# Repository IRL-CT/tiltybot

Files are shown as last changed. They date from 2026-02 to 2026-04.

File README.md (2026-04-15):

# TiltyBot

A smartphone-controlled robot platform built on the ESP32-S3 and Dynamixel XL330 servo motors. The robot hosts its own Wi-Fi network and serves a browser-based control interface — no app install required.

Building on Rei Lee's [ConeBot](https://github.com/rei039474/ConeBot).

<p>
  ConeBot waddling
  Pan-tilt gyro control
  Two-wheeled drive mode
</p>

## Guides

- **[TiltyBot Intro](TiltyBot_Intro_EN.md)** — connect and use
- **[TiltyBot Assembly & Advanced](TiltyBot_Advanced_EN.md)** — build, flash, modify

## What it does

Connect your phone to the robot's Wi-Fi, open `https://192.168.4.1`, and pick a mode:

- **Drive** — joystick differential drive
- **Tilty** — phone gyro pan/tilt (Android) or manual sliders
- **2-Motor** — direct position control
- **Puppet** — one robot mirrors another via ESP-NOW
- **Sound** — TTS, soundboard, recording
- **Calibrate** — set motor home position and limits

## Hardware

- [Waveshare ESP32-S3-Zero](https://www.waveshare.com/esp32-s3-zero.htm)
- 2× [Dynamixel XL330-M077-T](https://robotis.us/dynamixel-xl330-m077-t/)
- USB-C cable and power source

## Quick start

```bash
git clone https://github.com/imandel/tiltybot.git
cd tiltybot
pio run -e tiltybot -t upload
pio run -e tiltybot -t uploadfs
```

Connect your phone to the `BOT-*` Wi-Fi (password: `12345678`), open `https://192.168.4.1`.

## License

MIT

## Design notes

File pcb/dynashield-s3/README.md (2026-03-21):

# Dynashield S3

PCB adapter board for mounting a Waveshare ESP32-S3-Zero underneath, with a Dynamixel XL330 connector on top.

## Setup

1. Download the ESP32-S3-Zero part from [SnapEDA](https://www.snapeda.com/parts/ESP32-S3-Zero/Waveshare%20Electronics/view-part/)
2. Import the `.kicad_sym` and `.kicad_mod` files into KiCad (Preferences → Manage Symbol/Footprint Libraries → Add)
3. Open `dynashield-s3.kicad_sch` in KiCad
4. Add the ESP32-S3-Zero symbol and the B3B-EH-ALFSN connector (from KiCad's built-in Connector library)

## Wiring

| ESP32-S3-Zero | Net | Dynamixel Connector |
|---|---|---|
| GPIO1 (pin 4, left side) | DATA | Pin 3 (Data) |
| GPIO2 (pin 5, left side) | DATA | Pin 3 (Data) |
| 5V (pin 1, top left) | VDD | Pin 2 (VDD) |
| GND (pin 2, top left) | GND | Pin 1 (GND) |

GPIO1 and GPIO2 are tied together on the PCB — they share the same net (DATA) which connects to the Dynamixel's half-duplex data line.

## Board layout

The ESP32-S3-Zero mounts on the **bottom** of the PCB using its castellated hole pads (pins 1 and 2 side — 5V, GND, 3V3, GP1-GP6). The Dynamixel connector sits on the **top**.

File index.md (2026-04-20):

# TiltyBot Lab

## What is TiltyBot?

TiltyBot is a small expressive robot you control from your phone's browser. It has two servo motors and a microcontroller.

TiltyBot

### Parts

- **ESP32-S3-Zero** — a small Wi-Fi microcontroller ([Waveshare](https://www.waveshare.com/esp32-s3-zero.htm))
- **2× Dynamixel XL330-M077-T** — smart servo motors ([Robotis](https://robotis.us/dynamixel-xl330-m077-t/))
- **Hinge frame** — connects the two motors in a pan/tilt configuration ([Robotis](https://en.robotis.com/shop_en/item.php?it_id=903-0302-000))
- **USB-C battery pack**
- **Whatever you build around it** — cardboard, tape, etc

### How it's connected

```
   ┌─────────┐  USB-C  ┌──────────┐ 3-wire  ┌──────────┐ 3-wire  ┌──────────┐
   │ Battery ├────────►│ ESP32-S3 ├────────►│ Motor 1  ├────────►│ Motor 2  │
   └─────────┘         └────┬─────┘  bus    │  (Tilt)  │   bus   │  (Pan)   │
                            ┆               └──────────┘         └──────────┘
                            ┆ Wi-Fi
                            ┆ HTTPS
                       ┌────┴─────┐
                       │  Phone   │
                       │ (Browser)│
                       └──────────┘
 ```

The motors daisy-chain together on a single 3-wire bus (power + ground + data). The ESP32 runs a Wi-Fi network and HTTPS server which your phone connects to directly.

### The motors

These are [Dynamixel XL330-M077-T](https://robotis.us/dynamixel-xl330-m077-t/) servos. They're assembled in a pan/tilt configuration. You can think of it as:

- A **head and neck** — nod and look around
- A **torso and legs** — lean and twist
- A **short stubby snake** — two joints that wiggle

You can decide what each motor corresponds to.

### Set up

We've assembled the hardware, flashed the firmware, and calibrated each robot. 

- Firmware: [`src/tiltybot/main.cpp`](src/tiltybot/main.cpp)
- Web UI: [`data/`](data/) (HTML/CSS/JS served from the ESP32's filesystem)
- Full build/flash instructions: [TiltyBot Assembly & Advanced](TiltyBot_Advanced_EN.md)

---

## 1. Connect to Your Robot

Your robot automatically starts running when you connect it to power, and it is already serving a webpage which enables the robot to be remotely controlled. Look for the WiFi network with the same label as your robot.
Connect to it from a phone (android works best!):

1. Open Wi-Fi settings, find your robot's network (starts with `BOT-` and matches the sticky note color)
2. Password: `12345678`
3. Turn off your phone's cellular network
4. Open `https://192.168.4.1` in your browser
5. Accept the certificate warning (tap Advanced → Proceed)
6. You should see the TiltyBot menu served up by your robot

<p>
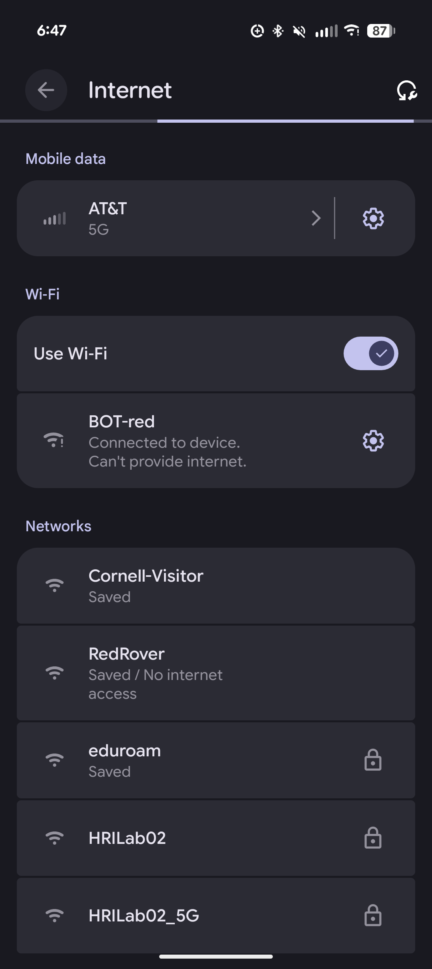
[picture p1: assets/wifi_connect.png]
Wi-Fi settings
  
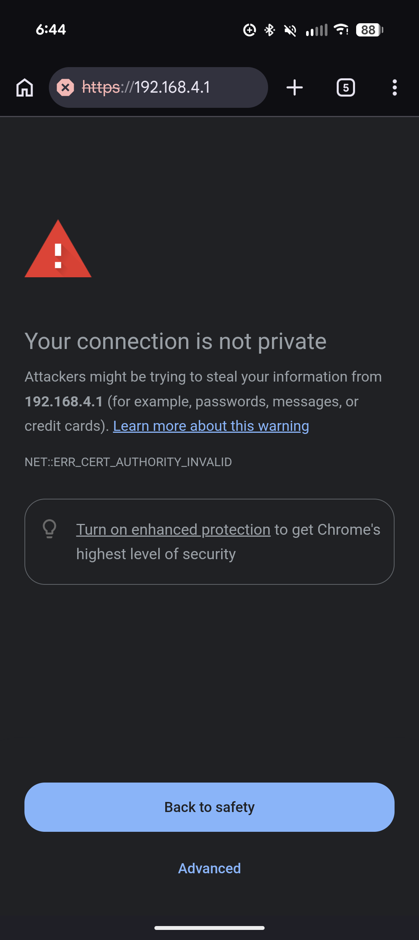
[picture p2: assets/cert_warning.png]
Certificate warning
  
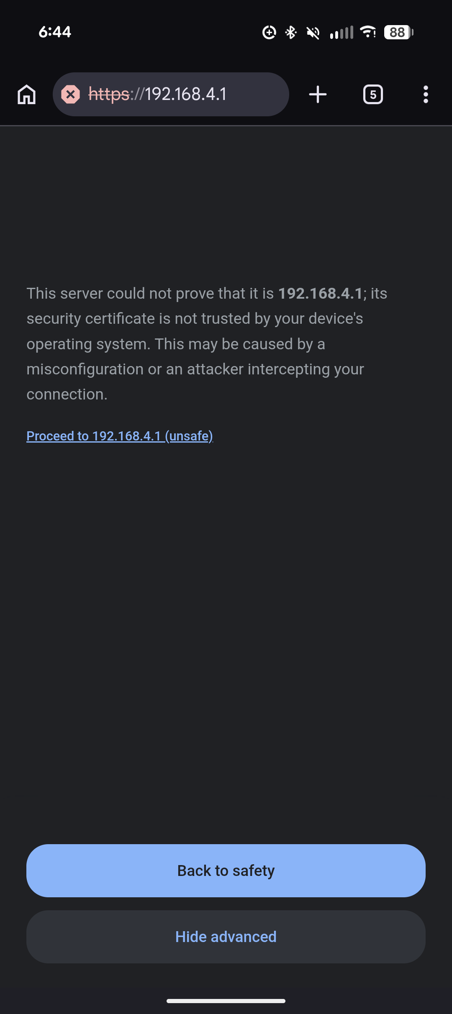
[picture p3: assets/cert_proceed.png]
Tap Proceed
  
</p>

You should see the TiltyBot menu:

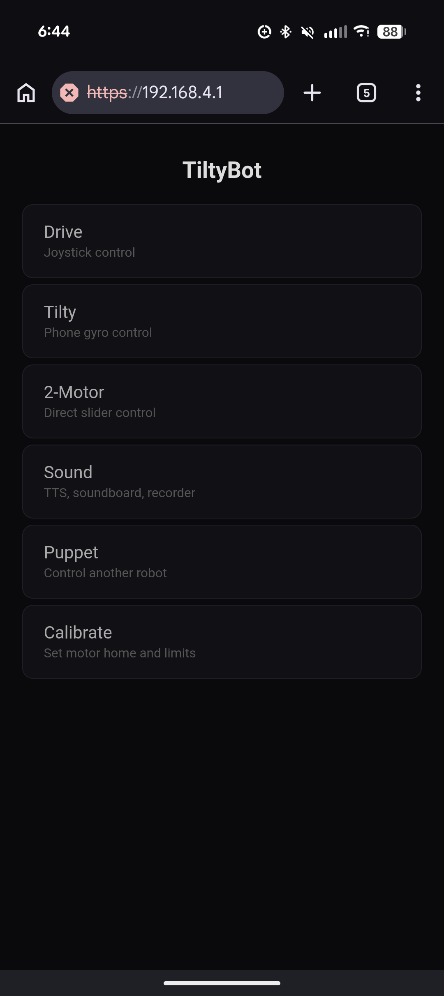
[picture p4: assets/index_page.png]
TiltyBot menu


---

## 2. Explore Motion

Your robot has several control modes. How you wizard a robot can shape what kinds of affect it can express. Try each of them and see what interactions feel natural.

### 2A. Tilty

Open **Tilty** from the menu. Use the sliders to control tilt (up/down) and pan (left/right).

With an Android phone, enable the **Gyro** checkbox. Your phone's orientation now controls the robot directly. Tilt and angle your phone to wizard the robot.

<p>
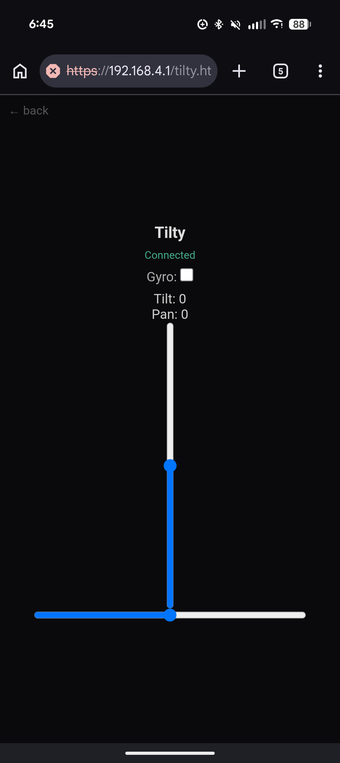
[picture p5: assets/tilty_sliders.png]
Tilty sliders
  
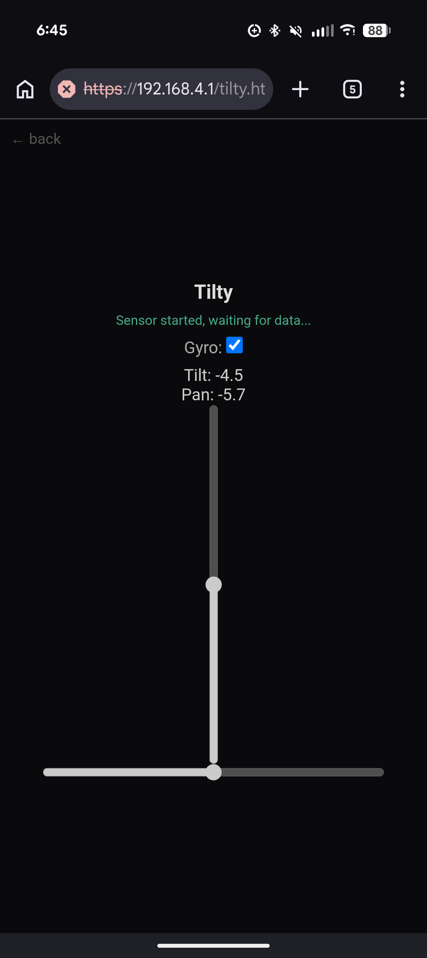
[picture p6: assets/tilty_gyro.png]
Tilty gyro
  
</p>

Tilty in action

> **Under the hood:** Gyro mode uses [`RelativeOrientationSensor`](https://developer.mozilla.org/en-US/docs/Web/API/RelativeOrientationSensor) to get hardware quaternions from the phone's IMU, then decomposes a delta quaternion into YXZ Euler angles. This avoids gimbal lock. If you're curious the math is in `data/tilty.html`.

### 2B. 2-Motor

Open **2-Motor** from the menu. Two sliders, one per motor. This gives you a clear understanding what each motor can do physically.

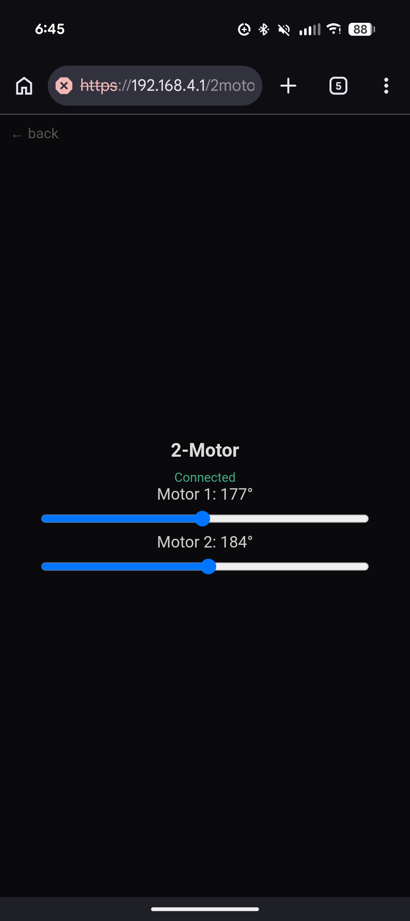
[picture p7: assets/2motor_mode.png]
2-Motor mode


### 2C.  Drive

If you are more interested in a mobile robot than a desktop robot, we have pre-assembled motor pairs configured for driving. Take them, unplug your tiltybot from the esp32 and plug the wheels in instead. You will have to attach the motors to a piece of cardboard to act as a base.

Open **Drive** from the menu. Check the **Active** box, then use the joystick to drive. The robot uses differential drive — both motors spinning the same direction turns, opposite directions goes straight.

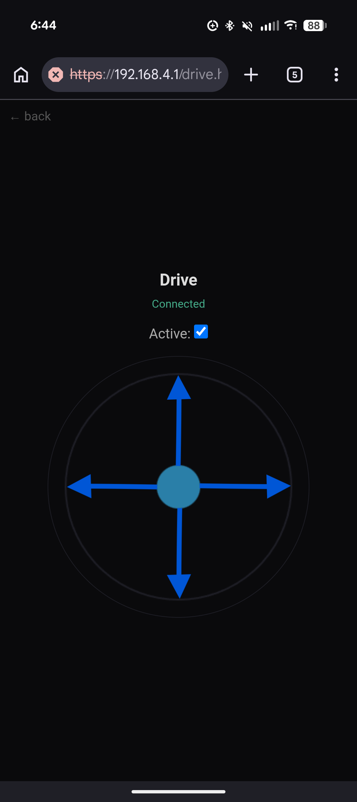
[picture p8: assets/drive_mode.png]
Drive mode


Drive demo

> **Under The Hood:**  A 300ms watchdog stops the motors if the client connection drops. Robots should ALWAYS use a watchdog timer.

### Questions

- How does each control mode change what the robot can express?
- What would you want the robot to do that you can't do yet?

---

## 3. Puppet Mode

Find another group. You'll pair two robots together. One will be the controller whicy you can direct by hand, the other will be a puppet and mirror its actions.

### Setup

1. On **both** robots, open the **Puppet** page
2. Pick the **same emoji** on both
3. One robot: tap **Controller** — its motors release, you move it by hand
4. Other robot: tap **Puppet** — it follows the controller's movements
5. Tap **Stop** on either robot when done

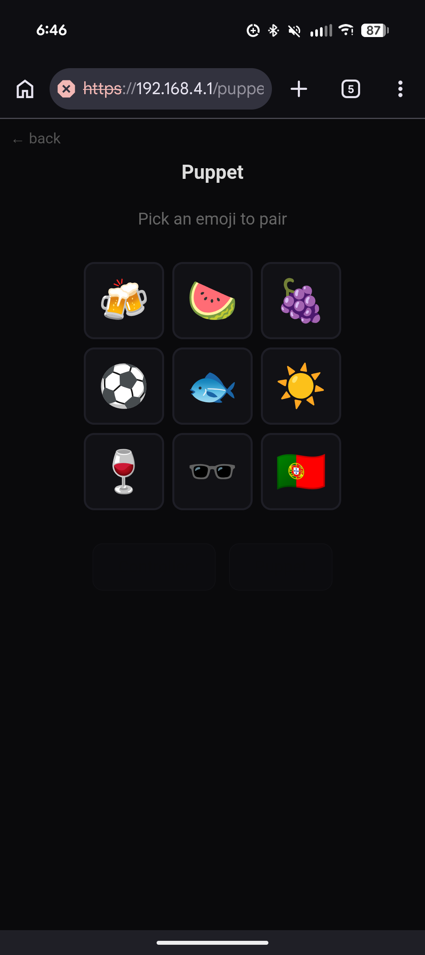
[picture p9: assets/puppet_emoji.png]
Puppet emoji selection


### Try it

- Have one person wizard the controller while someone from the other group interacts with the puppet
- Switch roles

> **Under The Hood:** Puppet mode uses ESP-NOW, a peer-to-peer wireless protocol that runs alongside Wi-Fi with ~1–5ms latency. The controller reads motor positions, converts to degrees, and broadcasts at ~100Hz. The puppet converts back using its own calibration. See the `PuppetPacket` struct in `main.cpp`. You can puppet multiple robots simultaneously. How would the interaction change with two, three, five, fivehundred tiltybots?

---

## 4. Sound

**When you get to this step ask Ilan for a speaker.**

Sound mode is designed for a **second operator**. One person controls the robot's movement (any mode), while another person triggers sounds from a second phone connected to the same robot.

### Setup

1. Connect a second phone to the same `BOT-*` network
2. Connect your phone's Bluetooth to the speaker. The speaker should show up as `MT`
3. Open **Sound** from the menu
4. Allow microphone access if prompted
5. Turn the speaker on and put it in pairing mode by holding the button on the bottom until the light flashes.

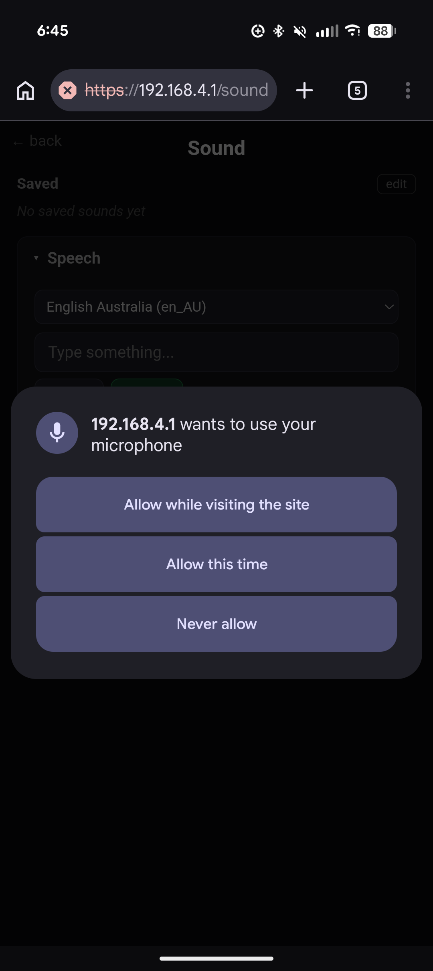
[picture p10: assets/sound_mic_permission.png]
Microphone permission


### What's available

- **Speech** — type text, pick a voice, tap Speak. Tap + Save to keep phrases for quick access.
- **Soundboard** — 24 synthesized robot sounds (beeps, chirps, affirmations, etc). Tap to play, tap + to save to the top bar.
- **Record** — record from the microphone or load audio files from your phone.

You can find sounds all over the internet. I am a fan of https://freesound.org/

Saved sounds appear in the **Saved** section at the top for one-tap playback during an interaction.

<p>
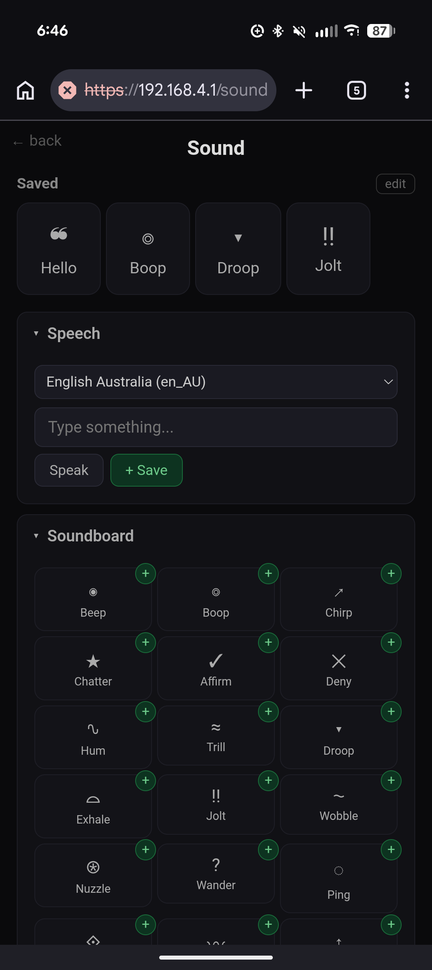
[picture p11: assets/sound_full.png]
Sound page
  
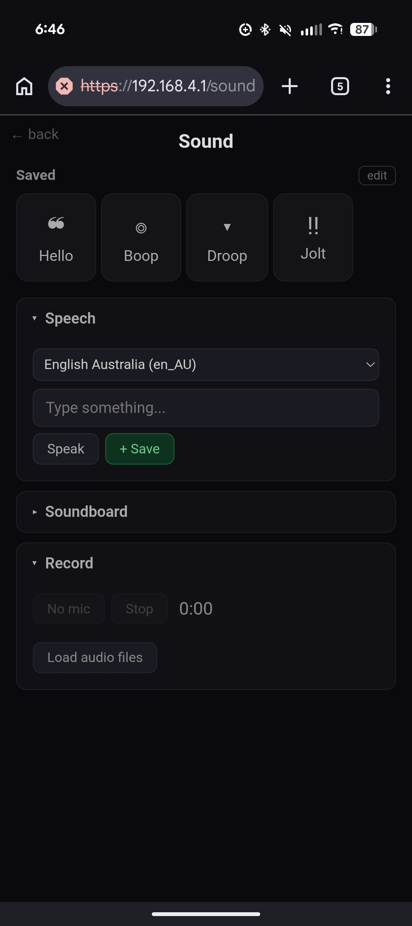
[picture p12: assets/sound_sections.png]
Sound sections
  
</p>

### Try it

- One person drives or puppets, the other does sound
- Practice synchronizing your actions. Plan out what motions and sounds should occur in tandem. Try doing improv with another member of your group. 
- Try an interaction with just motion, then just sound then try combining them.

### Questions
- When does sound help? When does it get in the way?
- How does operating two channels (motion + sound) change wizarding?

> **Under the hood:** TTS uses the browser's built-in [`SpeechSynthesis`](https://developer.mozilla.org/en-US/docs/Web/API/SpeechSynthesis) API. Soundboard effects are generated with the Web Audio API ([`OscillatorNode`](https://developer.mozilla.org/en-US/docs/Web/API/OscillatorNode), [`BiquadFilterNode`](https://developer.mozilla.org/en-US/docs/Web/API/BiquadFilterNode), etc). See `data/sound.html`.

---

## 5. Design an Interaction

Use what you've explored to design a short interaction.

How would a tiltybot take your order at a restuarant? How might it direct you to the right classroom in driving mode?

ConeBot

### Pick your setup

- Which control mode?
- Who is the robot interacting with? Someone from your group? A stranger?
- What is the context?
- What is the robot's role? 

### Design it

- What happens? Write down 2–3 sentences describing the interaction.
- What is the robot doing and why?
- What do you expect the person to do?

### Run it

- Try it at least once within your group
- Then try it with someone who wasn't involved in the design
- Did people respond the way you expected?
- What would you change?
- What did the control mode make easy or hard?

---

*— Coffee break —*

---

## 6. Check-in

Brief group share. What did you try? What didn't work?

---

## 7. Refine and Record

You have the rest of the afternoon to iterate on your interaction and capture it on video.

### Goals

- Refine your interaction based on what you learned
- Try it with people! 
- - Try a different setting (hallway, doorway, desk, open space)
- **Record video** — capture the full interaction, not just the robot. Include the person's reactions and the context.
- These can be naturalistic or acted. You want to clearly explore the *interaction*
- What research questions did these explorations inspire?
- You'll present these tomorrow

> If you're interested in automating interactions, modifing the control interfaces or extending tiltybot talk to Ilan about it!

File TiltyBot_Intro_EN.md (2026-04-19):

# TiltyBot Intro

## [TiltyBot Assembly & Advanced →](TiltyBot_Advanced_EN.md)

## What TiltyBot Is

TiltyBot is a small robot built from an ESP32-S3 microcontroller and two Dynamixel XL330 servo motors. It can be assembled as a mobile robot or a minimalist desktop robolt.

The robot runs its own Wi-Fi network and serves a phone browser-based control interface.

TiltyBot overview

ConeBot demo

## How to Connect

1. On your phone, open Wi-Fi settings and look for a network starting with `BOT-` (e.g., `BOT-red`, `BOT-blue`)

2. Connect to it. The password is `12345678`. Your phone will say it can't provide internet. Turn of cellular data.

Wi-Fi settings showing BOT-red

3. Open a browser and go to `https://192.168.4.1`

4. You will see a certificate warning. Tap **Advanced**, then **Proceed to 192.168.4.1 (unsafe)**. The robot uses a self-signed certificate so the browser can access phone sensors like the gyroscope.

Certificate warning

Tap Advanced, then Proceed

5. You should see the TiltyBot main menu:

TiltyBot index page

## Modes

### Drive

Differential drive control using an on-screen joystick. Click the checkbox to activate the motors, then touch and drag to steer.

Drive mode

Drive demo

### Tilty (Android only)

Controls the robot's pan and tilt using your phone's orientation. Hold your phone and tilt it — the robot follows.

> Gyro control requires an Android device. Manual sliders are available on any device as a fallback.

**Before using Tilty mode, calibrate the robot.**

Open the Calibrate page from the main menu:

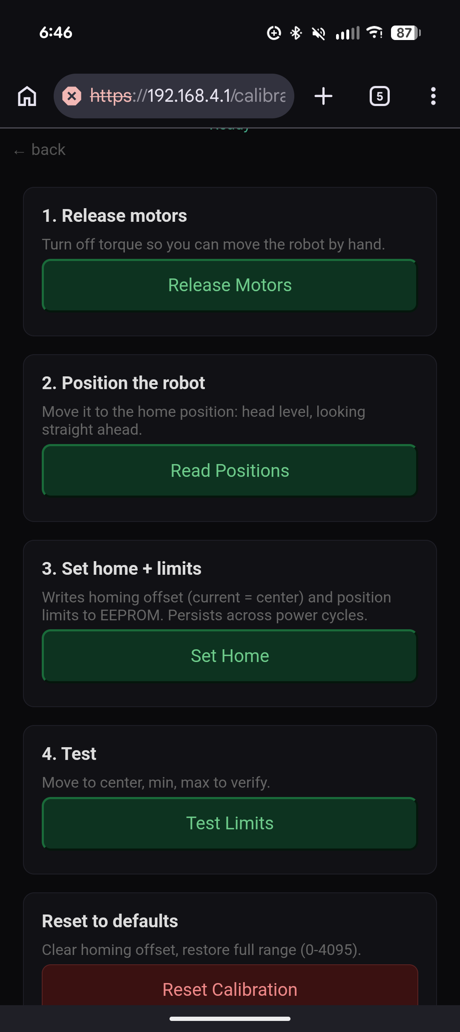
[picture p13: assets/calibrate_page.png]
Calibrate page


1. Tap **Release Motors** — this turns off motor torque so you can move the head by hand
2. Physically position the robot's head to the desired neutral pose: level, facing straight ahead
3. Tap **Read Positions** to confirm the motor values
4. Tap **Set Home** — this writes the current position as the new center to motor memory
5. Tap **Test Limits** — the robot moves through its range so you can verify it looks correct

Calibration persists across power cycles. You only need to redo it if you physically reassemble the robot.

Once calibrated, open Tilty mode. Use the sliders for manual control:

Tilty mode with sliders

Or enable the **Gyro** checkbox to control with phone orientation:

Tilty mode with gyro enabled

Tilty demo

### 2-Motor

Direct slider control of both motors independently. Useful for testing motor response or exploring range of motion.

2-Motor mode

### Puppet (two bots)

One robot mirrors another's movements in real time. You move the controller robot by hand, and the puppet robot follows.

**Setup:**

1. Open the Puppet page on both robots (from two phones, each connected to its own bot's Wi-Fi)
2. Pick the **same emoji** on both robots

Puppet emoji selection

3. On one robot, tap **Controller** — its motors release so you can move it by hand
4. On the other robot, tap **Puppet** — it begins following the controller's movements
5. Tap **Stop** on either robot to end

For best results, calibrate both robots before using puppet mode.

### Sound

We provide a basic audio control interface for use with a small bluetooth speaker. You can do text-to-speech, a "robot" soundboard, audio recording, and file playback.

Sound mode is designed for a **second operator**. One person controls the robot's movement (via Drive, Tilty, or Puppet) while another person operates Sound mode from a second phone connected to the same robot.

The first time you open Sound, your browser will ask for microphone permission. Tap **Allow while visiting the site** if you want to use the recorder.

Microphone permission

Sound page with saved sounds and all sections

Sound page showing collapsed sections

## If Something Doesn't Work

| Problem | Try |
|---|---|
| Can't find the Wi-Fi network | Make sure you're close to the robot and it's powered on |
| Page won't load | Confirm you're on the `BOT-*` network, go to `https://192.168.4.1` |
| Certificate error won't go away | Try a different browser (Chrome works best) |
| Motors don't respond | Reload the page, or try 2-Motor mode to check basic connectivity |
| Tilty gyro doesn't work | Confirm you're on an Android device. Toggle the Gyro checkbox off and on |
| Puppet doesn't follow | Check both robots selected the same emoji. Recalibrate both |
| Robot behaves strangely after reassembly | Recalibrate |

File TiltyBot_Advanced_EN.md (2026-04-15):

# TiltyBot Assembly & Advanced

## Hardware

- [Waveshare ESP32-S3-Zero](https://www.waveshare.com/esp32-s3-zero.htm) (ESP32-S3, 4MB Flash, 2MB PSRAM)
- 2× [Dynamixel XL330-M077-T](https://robotis.us/dynamixel-xl330-m077-t/) servo motors
- [XL330 Hinge Frame](https://www.robotis.us/fpx330-h101-4pcs-set/)
- USB-C cable
- Wheels, caster wheels
- Cardboard, tape, and whatever else you want to build with

### Wiring

The motors daisy-chain together and connect to the ESP32-S3-Zero via 3 wires:

| Dynamixel XL330 Pin | Signal | ESP32-S3-Zero |
|---|---|---|
| Pin 1 — GND | Ground | **GND** |
| Pin 2 — VDD | Power (5V) | **5V** |
| Pin 3 — Data | Half-duplex serial | **GPIO1 + GPIO2** (tied together) |

GPIO1 (TX) and GPIO2 (RX) are next to each other on the left side of the board. Both connect to the single Dynamixel Data wire for half-duplex communication.

## Software Setup

Install:

- [Git](https://git-scm.com/)
- [PlatformIO](https://platformio.org/) — either as a VS Code extension or CLI-only

Clone the repository:

```bash
git clone https://github.com/imandel/tiltybot.git
cd tiltybot
```

Verify the build:

```bash
pio run -e tiltybot
```

## Motor Setup

Each motor needs a unique ID. Flash the motor setup tool:

```bash
pio run -e motor_setup -t upload
pio device monitor -b 115200
```

Connect **one motor** at a time:

1. Connect Motor 1, type `1` → configures as ID 1 (LED blinks, motor moves to confirm)
2. Disconnect Motor 1, connect Motor 2, reset board, type `2` → configures as ID 2
3. Daisy-chain both motors, reset board, type `t` → runs full test

**Motor 1 = tilt** (nod up/down), **Motor 2 = pan** (rotate left/right).

## Build / Flash / UploadFS

Upload firmware:

```bash
pio run -e tiltybot -t upload
```

Upload web UI and certificates to the filesystem:

```bash
pio run -e tiltybot -t uploadfs
```

Both steps are needed when setting up a new robot. After that, you only need to re-upload whichever part you changed.

**If the ESP32-S3 won't enter download mode** (upload fails with "No serial data received"):

1. Hold **BOOT**
2. Tap **RESET**
3. Release **BOOT**
4. Retry the upload command

## Configuration (`BOT_SSID`)

Each robot's Wi-Fi network name is set at build time:

```bash
PLATFORMIO_BUILD_FLAGS='-DBOT_SSID="BOT-yourname"' pio run -e tiltybot -t upload
```

The default (if no flag is set) is defined in `main.cpp`:

```c
#define BOT_SSID "YOURGROUPNAME"
```

The Wi-Fi password is `12345678`.

## Project Layout

```
tiltybot/
├── src/
│   ├── tiltybot/main.cpp      # Main firmware (all control modes)
│   └── motor_setup/main.cpp   # Motor ID assignment utility
├── data/                      # Web UI (served from LittleFS)
│   ├── style.css              # Shared styles
│   ├── index.html             # Landing page
│   ├── drive.html             # Drive mode
│   ├── tilty.html             # Tilty mode
│   ├── 2motor.html            # 2-Motor mode
│   ├── puppet.html            # Puppet mode
│   ├── sound.html             # Sound mode
│   └── calibrate.html         # Calibration
├── certs/                     # Self-signed SSL certificates
├── partitions.csv             # Custom partition table (4MB flash)
└── platformio.ini             # Build configuration
```

## System Architecture

- The ESP32 runs as a **Wi-Fi access point** and HTTPS server
- Web pages are stored on **LittleFS** and served to the browser
- Browser control pages communicate with the firmware over **WebSocket**
- Each mode has its own WebSocket endpoint (`/ws/drive`, `/ws/tilty`, `/ws/2motor`)
- Drive mode uses **Dynamixel Sync Write** to update both motors in a single bus packet
- Tilty mode uses `RelativeOrientationSensor` (Android) with delta quaternion decomposition for gimbal-lock-free pan/tilt control
- Puppet mode uses **ESP-NOW** for direct robot-to-robot communication (~1–5ms latency, ~100Hz). Emoji selection acts as a pairing filter. Packets carry angles in degrees; each robot maps through its own calibration

## Debugging / Logs

```bash
pio device monitor -b 115200
```

Key log lines:

| Log prefix | Meaning |
|---|---|
| `Motor mode -> DRIVE/POSITION` | Mode switch on WebSocket connect |
| `DRIVE moving: ...` | Joystick input started |
| `DRIVE -> stop: ...` | Joystick released, writing zeros |
| `DRIVE watchdog: ...` | No client frame for 300ms, emergency stop |
| `DRIVE X.XHz ...` | Periodic drive status (every 2s) |
| `TILTY ...` | Tilty/2-motor position update |
| `PUPPET TX: ...` | Controller broadcasting position |
| `ESP-NOW rx ...` | Puppet receiving data |
| `CALIB: ...` | Calibration operations |

If behavior seems wrong after physical changes, recalibrate before deeper debugging.

## CLI Reference

```bash
# Build
pio run -e tiltybot
pio run -e motor_setup

# Upload
pio run -e tiltybot -t upload
pio run -e tiltybot -t uploadfs
pio run -e motor_setup -t upload

# Custom SSID
PLATFORMIO_BUILD_FLAGS='-DBOT_SSID="BOT-red"' pio run -e tiltybot -t upload

# Specify port
pio run -e tiltybot -t upload --upload-port /dev/cu.usbmodem101

# Monitor
pio device monitor -b 115200

# Clean / erase
pio run -e tiltybot -t clean
pio run -e tiltybot -t erase
```

## Dependencies

Managed automatically by PlatformIO (see `platformio.ini`):

- [PsychicHttp](https://github.com/hoeken/PsychicHttp) — HTTPS server with WebSocket support
- [Dynamixel_XL330_Servo_Library](https://github.com/rei039474/Dynamixel_XL330_Servo_Library.git) — Motor control
- [ArduinoJson](https://github.com/bblanchon/ArduinoJson) — JSON parsing

## Notes

- HTTPS is required for gyroscope access — browsers only allow sensor APIs in secure contexts
- Turn off cellular data on your phone so it doesn't drop the robot's network
- Corporate/managed phones may not work due to network restrictions
- To regenerate the SSL certificate:
  ```bash
  openssl req -x509 -newkey ec -pkeyopt ec_paramgen_curve:prime256v1 \
    -keyout data/server.key -out data/server.crt -days 3650 -nodes \
    -subj "/CN=tiltybot.local"
  ```

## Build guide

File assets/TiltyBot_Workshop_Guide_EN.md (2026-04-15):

# TiltyBot Workshop Guide

A hands-on workshop for building and interacting with a smartphone-controlled robot using an ESP32-S3, Dynamixel motors, and open-source software.

---

## Table of Contents

1. [Preparation](#1-preparation)
2. [Software Setup — Building the Base Robot](#2-software-setup--building-the-base-robot)
3. [Hardware Assembly](#3-hardware-assembly)
4. [Calibration](#4-calibration)
5. [Puppet Mode](#5-puppet-mode)
6. [Interaction Design](#6-interaction-design)

---

## 1. Preparation

This section covers everything you need to do before the workshop begins. If you get stuck on any step, don't worry — these can also be completed in person at the start of the workshop.

### Before You Begin

- You will use a **personal smartphone** to control the robot. Corporate/managed phones may not work due to security restrictions.
- **Gyro tilty mode requires Android** (uses RelativeOrientationSensor). Manual sliders work on any device.

### Step 1: Install Tools

You can use VS Code with PlatformIO, or just the CLI.

**Option A: VS Code** (recommended for beginners)

- [Visual Studio Code](https://code.visualstudio.com/)
- [PlatformIO](https://platformio.org/) extension — install from VS Code Extensions tab
- [Git](https://git-scm.com/download/win) (Windows) / Git is pre-installed on most Macs

**Option B: CLI only**

- [Git](https://git-scm.com/)
- PlatformIO Core:
  ```bash
  pip install platformio
  # or
  curl -fsSL -o get-platformio.py https://raw.githubusercontent.com/platformio/platformio-core-installer/master/get-platformio.py
  python3 get-platformio.py
  ```

### Step 2: Clone the TiltyBot Repository

Clone the project repository to a convenient location on your computer (e.g., your Desktop).

1. Open a terminal (or right-click your desired folder and select **Git Bash Here** on Windows).

<!-- TODO: update screenshot for new repo -->
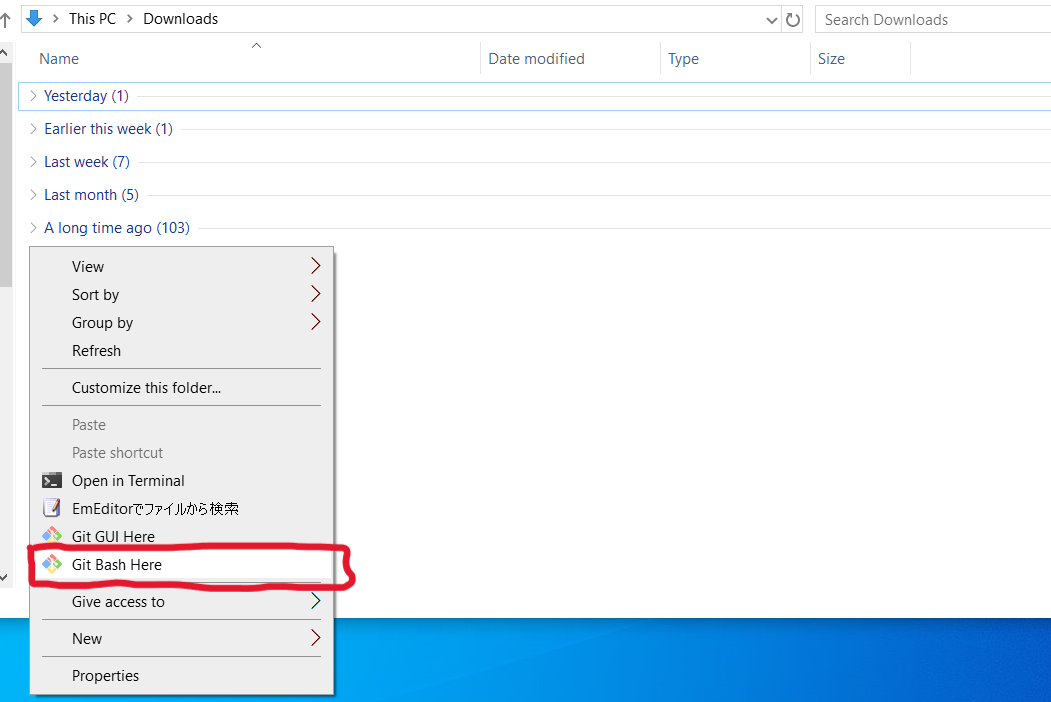
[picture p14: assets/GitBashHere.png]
Opening Git Bash from a folder


2. Run the following command:

```
git clone https://github.com/imandel/tiltybot.git
```

### Step 3: Install PlatformIO (VS Code only)

If using VS Code:

1. Go to **View → Extensions**. Search for **PlatformIO** and install it.
2. Click the PlatformIO icon (ant icon) in the left sidebar to trigger initialization. Wait until it finishes.
3. Click **Reload Now** when prompted.

### Step 4: Build the Project

**VS Code:** Open the `tiltybot` folder in PlatformIO, then click the **Build button** (checkmark at the bottom).

**CLI:**

```bash
cd tiltybot
pio run -e tiltybot
```

Wait for "SUCCESS." Preparation is now complete!

---

## 2. Software Setup — Building the Base Robot

### Step 1: Configure Motors

Each Dynamixel motor needs a unique ID. We'll use a setup tool to assign them.

**Important:** Motor 1 = **tilt** (nod up/down), Motor 2 = **pan** (rotate left/right).

1. Upload the motor setup tool:

   ```bash
   pio run -e motor_setup -t upload
   ```

2. Open the Serial Monitor:

   **VS Code:** Click the plug icon at the bottom status bar.

   **CLI:**
   ```bash
   pio device monitor -b 115200
   ```

   You'll see:

```
========================================
  TILTYBOT MOTOR SETUP
========================================

Options:
  1 - Configure this motor as Motor 1
  2 - Configure this motor as Motor 2
  t - Test both motors (daisy-chained)
```
If not press the reset button on the ESP32 while connected to the serial monitor.

3. With **one motor connected**, type `1` and press Enter. The motor's LED will blink and it will rotate back and forth to confirm.

4. Disconnect the first motor. Connect the **second motor**. Reset the board (press the reset button or unplug/replug USB). Type `2` and press Enter.

5. Daisy-chain both motors together (plug Motor 2 into Motor 1's other port, Motor 1 connects to the board). Reset the board. Type `t` to run the full test:
   - Both LEDs blink individually
   - Position mode: both motors move through several positions
   - Drive mode: both motors spin forward, backward, slow, and max speed

If the test passes, your motors are ready!

### Step 2: Set Wi-Fi Name

The robot hosts its own local Wi-Fi network (no internet required). You'll connect your phone to this network to control the robot.

Set the SSID at build time:

```bash
PLATFORMIO_BUILD_FLAGS='-DBOT_SSID=\"BOT-yourname\"' pio run -e tiltybot -t upload
```

Or edit `src/tiltybot/main.cpp` directly and change:

```c
#define BOT_SSID "YOURGROUPNAME"
```

The password defaults to `12345678` (must be 8+ characters).

### Step 3: Upload SSL Certificates and HTML Pages

The robot uses HTTPS so your phone's gyroscope can work in the browser. Upload the filesystem (SSL certificates + all HTML pages):

```bash
pio run -e tiltybot -t uploadfs
```

### Step 4: Upload Firmware

```bash
pio run -e tiltybot -t upload
```

Or with a custom SSID:

```bash
PLATFORMIO_BUILD_FLAGS='-DBOT_SSID=\"BOT-yourname\"' pio run -e tiltybot -t upload
```

### Step 5: Connect Your Phone to the Robot

1. On your phone, go to Wi-Fi settings and connect to the network you configured in Step 2. Ignore any "No Internet" warnings.

2. Open a browser and navigate to `https://192.168.4.1`

3. You'll see a security warning about the self-signed certificate. Tap **Advanced** → **Proceed** (or equivalent for your browser).

4. The index page shows all available modes — pick one!

<!-- TODO: screenshot of index page on phone -->

**Tips:**
- Turn off cellular data on your phone to prevent it from automatically switching away from the robot's network.
- Disconnect from any VPN before connecting.

### Step 6: Test the 2-Motor Mode

Start with **2-Motor mode** to verify everything works. Move the sliders — both motors should respond.

You're now ready to assemble.

---

## 3. Hardware Assembly

Choose one of the two robot types to build:

| Driving Robot | Tilty Robot |
|---|---|
| Mobile robot on wheels | Dashboard robot that tilts and pans |

### Wiring

Connect the ESP32-S3-Zero to the Dynamixel motors:

| Dynamixel XL330 Pin | Signal | ESP32-S3-Zero |
|---|---|---|
| Pin 1 — GND | Ground | **GND** |
| Pin 2 — VDD | Power (5V) | **5V** |
| Pin 3 — Data | Half-duplex serial | **GPIO1 + GPIO2** (tied together) |

<!-- TODO: photo of wiring close-up -->

The two motors daisy-chain together — connect Motor 2 to the other port on Motor 1.

### Driving Robot

1. **Attach axles:** Screw the white axle pieces onto each motor using the provided screws.

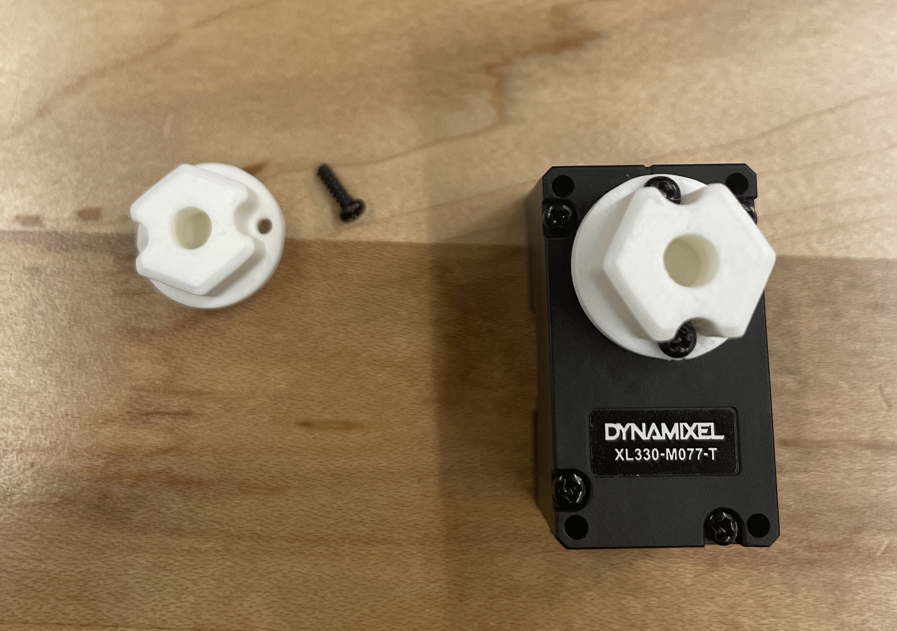
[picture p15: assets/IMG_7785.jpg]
Motor with axle piece

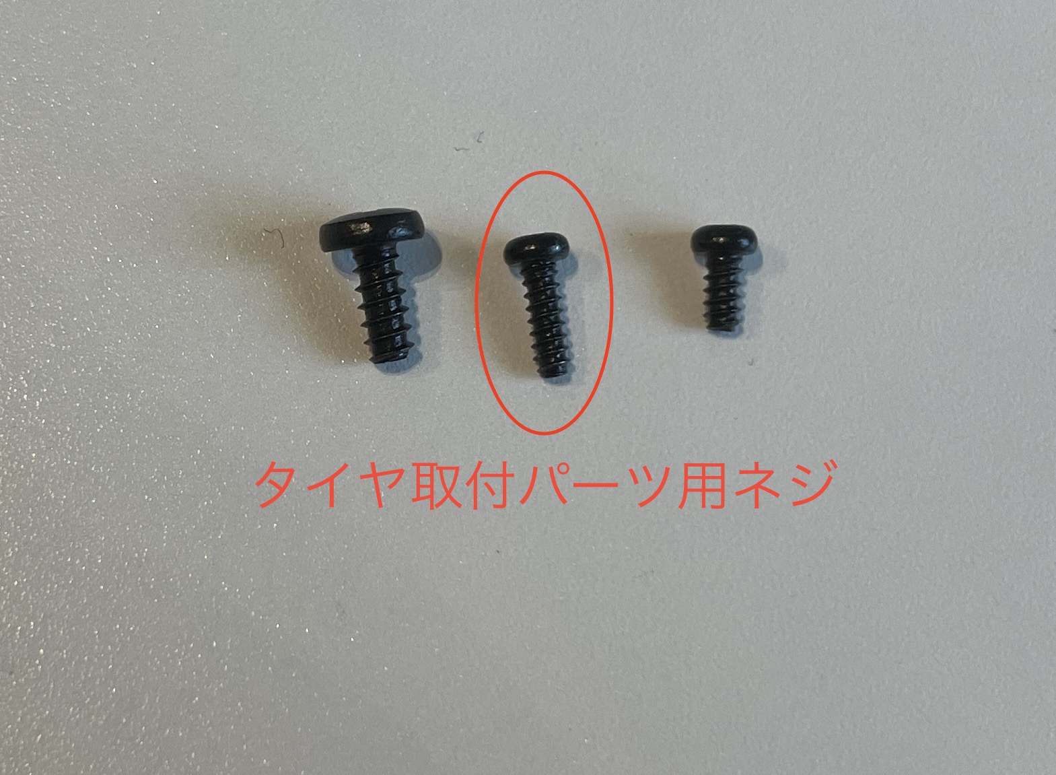
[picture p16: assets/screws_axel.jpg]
Axle screws


2. **Attach wheels:** Insert the axles into the wheels.

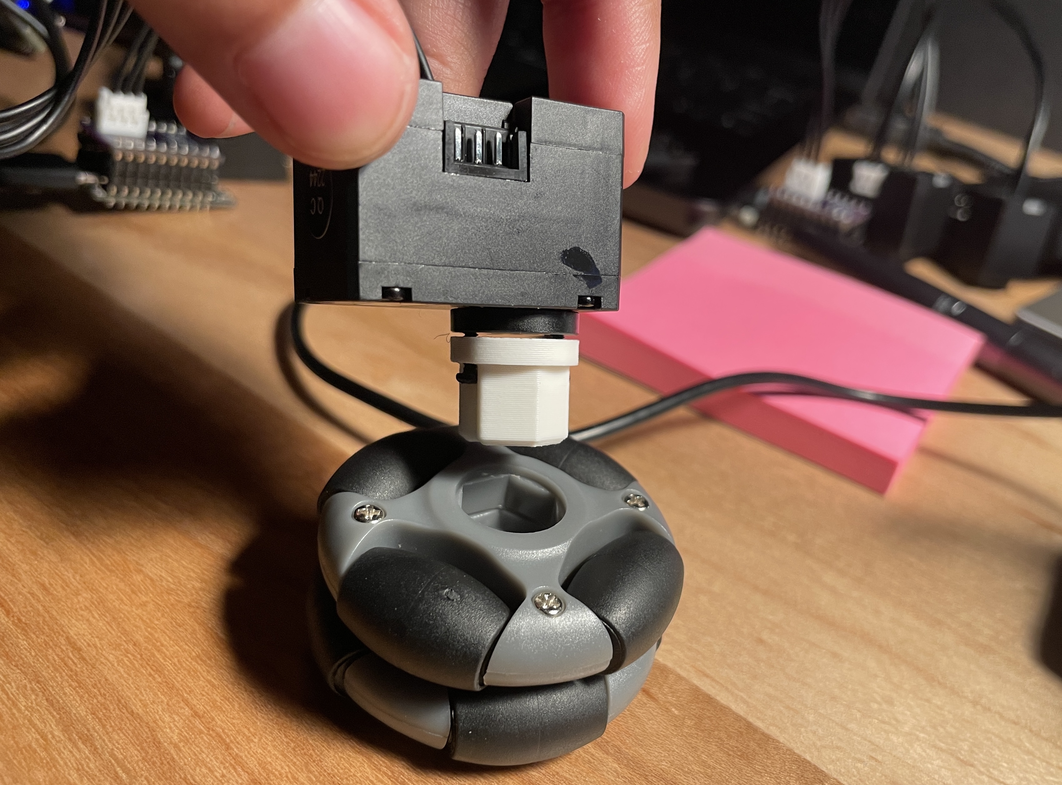
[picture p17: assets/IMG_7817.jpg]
Wheel attached to axle


3. **Build a base:** Use cardboard (or similar material) to create a platform for mounting.

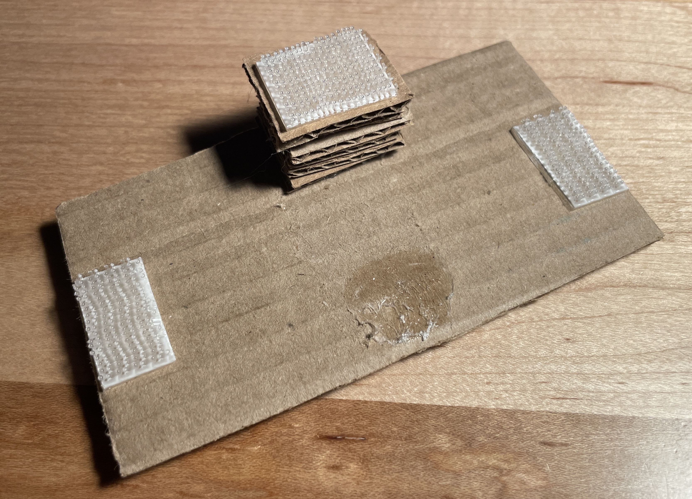
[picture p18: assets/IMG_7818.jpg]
Cardboard base


4. **Mount components:** Attach both Dynamixel motors and a roller ball to the base. Position them in a triangle for balance.

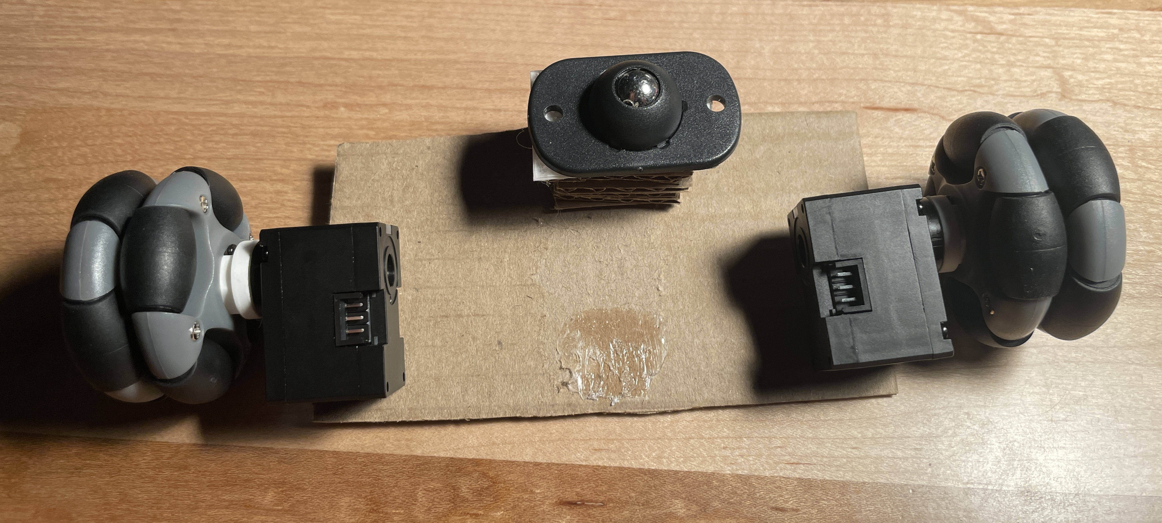
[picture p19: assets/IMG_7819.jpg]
Motors and roller ball mounted

Completed drive robot base

5. **Connect and drive:** Join the robot's Wi-Fi, open `https://192.168.4.1`, tap **Drive Mode**, check **Active**, and use the joystick.

Drive mode in action

### Tilty Robot

1. **Attach the head:** Screw the hinge bracket to **Motor 1** using the short screws.

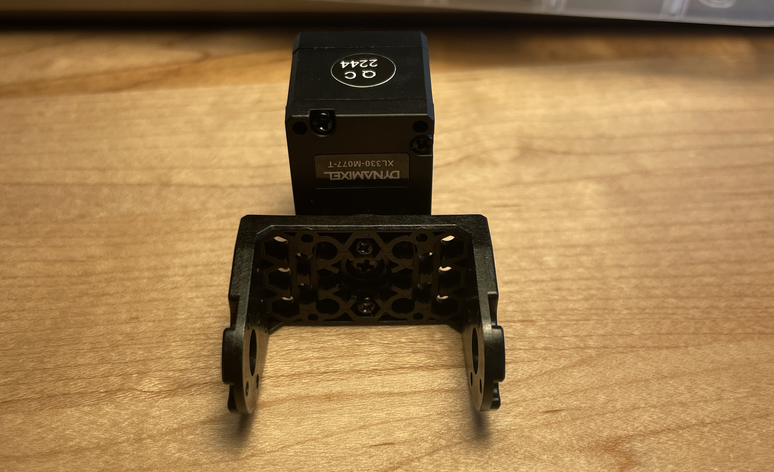
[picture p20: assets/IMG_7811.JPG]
Head attached to Motor 1

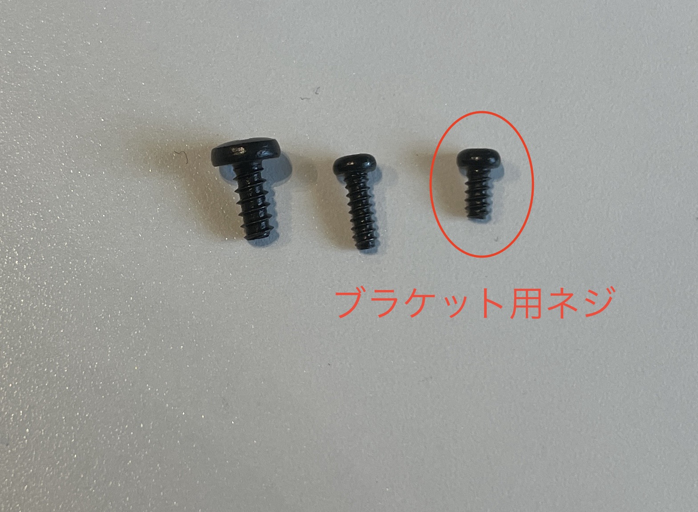
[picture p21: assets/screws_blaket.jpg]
Bracket screws


2. **Attach the idler:** On **Motor 2**, attach only the idler and idler cap.

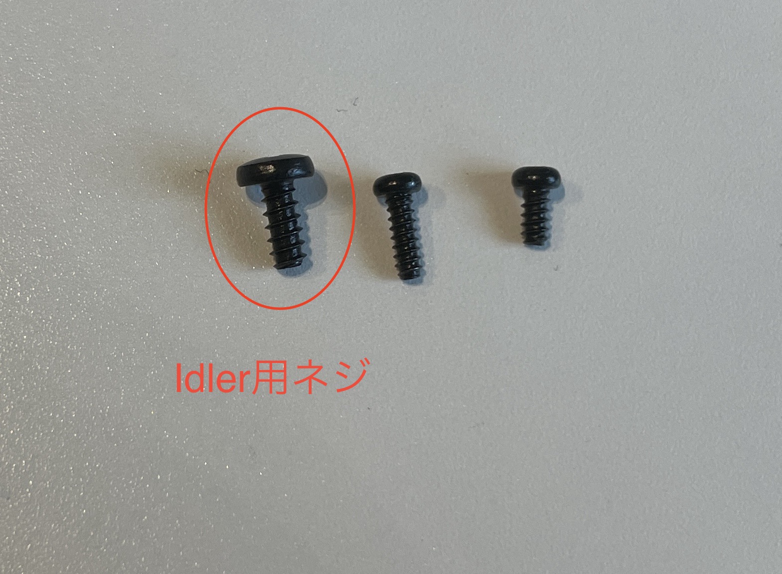
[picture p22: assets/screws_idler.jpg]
Idler screws


3. **Combine:** Attach the head/hinge assembly to Motor 2 (the LED on top of Motor 2 should face you). Don't worry about the exact angle — you'll calibrate after assembly.

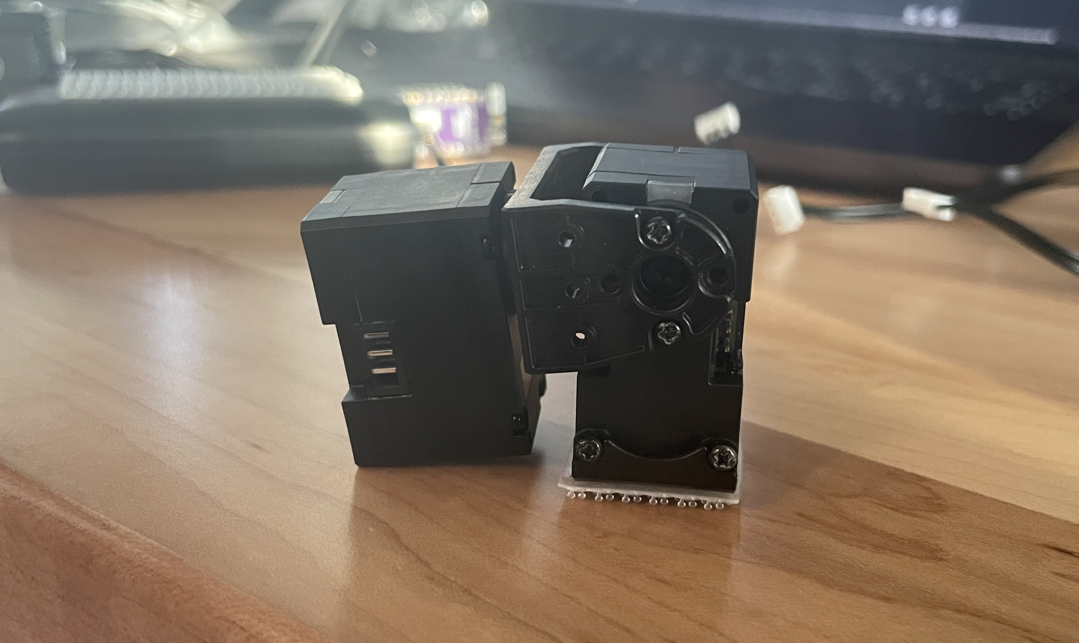
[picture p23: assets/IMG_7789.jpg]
Correct assembly orientation


4. **Connect and tilt:** Join the robot's Wi-Fi, open `https://192.168.4.1`, tap **Tilty Mode**. Use the sliders, or enable **Gyro** to control with your phone's orientation (Android only).

Tilty mode in action

---

## 4. Calibration

After assembling the robot, calibrate so that the center position (2048) corresponds to "head level, looking straight ahead." Calibration writes to motor EEPROM and persists across power cycles.

### Why calibrate?

Every robot is assembled slightly differently. Without calibration, "center" might mean the head is tilted or rotated. Calibration also sets position limits to prevent the head from hitting the body.

### Procedure

1. Connect to the robot's Wi-Fi and open `https://192.168.4.1/calibrate.html`

2. **Release Motors** — click the button to turn off torque. You can now move the robot's head freely by hand.

3. **Position the robot** — physically move the head to the desired home position: level, facing straight ahead. Click **Read Positions** to see the raw motor values.

4. **Set Home** — click to write the homing offset to EEPROM. This makes the current position the new center (2048). Also sets default position limits (1024–3072, which is ±90° from center).

5. **Test Limits** — the robot moves to center, minimum, and maximum positions so you can verify the range looks correct.

6. If needed, **Reset** clears calibration back to factory defaults.

### Setting tilt limits for body clearance

The default ±90° tilt range may cause the head to collide with the robot's body. To find and set the actual safe range:

1. Release motors on the calibrate page
2. Gently move the tilt motor until it just touches the body in each direction
3. Read the positions at each extreme — note the values
4. These will be your tilt position limits

<!-- TODO: add UI for setting custom per-axis position limits -->

### Notes

- Always calibrate **after** assembly — the physical orientation depends on how the parts are mounted.
- Homing offset range is ±1024 (±90°). If the offset exceeds this, the motor silently ignores it.
- Both robots must be calibrated for puppet mode to work correctly — "center" must mean the same physical pose on both.

---

## 5. Puppet Mode

Puppet mode lets one robot mirror another's movements in real-time. Move the "controller" robot by hand, and the "puppet" robot follows.

### Requirements

- Two assembled and **calibrated** robots
- Both flashed with the same firmware (different SSIDs)
- Both powered on

### Setup

1. **Flash both robots** with different SSIDs so you can tell them apart:
   ```bash
   pio run -e tiltybot -t upload --upload-port /dev/cu.usbmodem1301
   PLATFORMIO_BUILD_FLAGS='-DBOT_SSID=\"BOT-red\"' pio run -e tiltybot -t upload --upload-port /dev/cu.usbmodem12301
   ```

2. **Calibrate both robots** (see [Calibration](#4-calibration) above). This is important — puppet mode sends angles in degrees, and each robot converts to its own motor positions.

3. **Set up the controller:**
   - Connect your phone to robot A's Wi-Fi
   - Open `https://192.168.4.1/puppet.html`
   - Pick an emoji (e.g., 🍻)
   - Tap **Controller**
   - The motors release — you can now move robot A by hand

4. **Set up the puppet:**
   - Connect your phone to robot B's Wi-Fi
   - Open `https://192.168.4.1/puppet.html`
   - Pick the **same emoji** (🍻)
   - Tap **Puppet**
   - Robot B starts following robot A's movements

5. **Stop:** tap the Stop button on either robot's puppet page.

### How it works

- The controller reads its motor positions, converts to degrees from center, and broadcasts via **ESP-NOW** (~100Hz)
- The puppet receives the angle data and converts to its own motor positions using its own calibration
- ESP-NOW is peer-to-peer wireless that works alongside WiFi with ~1-5ms latency
- Both APs must be on the same WiFi channel (both default to channel 1)
- The emoji is a simple pairing mechanism — only robots with the same emoji respond to each other

---

## 6. Interaction Design

Now that your robot is built, it's time to think about how people will interact with it. This section guides you through a design thinking exercise.

### Overview

A. [Plan](#part-a-plan)
B. [Act Out the Interaction](#part-b-act-out-the-interaction)
C. [Design the Appearance](#part-c-design-the-appearance)
D. [Control the Device](#part-d-control-the-device)
E. [Record](#part-e-record)

### Part A: Plan

Think about the interaction you want to create. Consider these four elements:

1. **Setting:** Where and when does this interaction take place? (e.g., a kitchen, a hospital, outdoors)
2. **Players:** Who is involved? Think about all the people present — the primary user, bystanders, children, roommates, etc. Poor designs often fail because they don't account for everyone in the environment.
3. **Activity:** What happens between the players and the robot?
4. **Goals:** What is each player trying to accomplish?

Write down your setting, players, activity, and goals.

### Part B: Act Out the Interaction

Physically act out the scenario you planned — without the robot. Have someone pretend to be the device and perform its scripted actions.

After acting it out, reflect:

- Did anything work better on paper than in practice?
- Did any new ideas or insights emerge from the performance?

### Part C: Design the Appearance

Now consider what the robot should look like. Think about:

- The environment: Could it overheat? Is water a risk? Does it need to be visible in emergencies?
- The users: What form factor would feel natural and inviting for the people who will interact with it?

Sketch your design on paper, then build a physical prototype using craft materials (cardboard, tape, markers, etc.).

### Part D: Control the Device

Practice controlling the robot so it performs the actions from your scenario. Have one person operate the controller while another interacts with the robot as a user.

### Part E: Record

Film a video of your prototyped interaction. Show the full scenario: the setting, the players, and the robot performing its role. This video captures the essence of your design idea and can be used for presentations or further iteration.

---

## Resources

- **TiltyBot Repository:** [https://github.com/imandel/tiltybot](https://github.com/imandel/tiltybot)
- **Visual Studio Code:** [https://code.visualstudio.com/](https://code.visualstudio.com/)
- **PlatformIO:** [https://platformio.org/](https://platformio.org/)
- **Git:** [https://git-scm.com/](https://git-scm.com/)

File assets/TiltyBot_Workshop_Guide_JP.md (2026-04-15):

# TiltyBot ワークショップガイド

<!-- TODO: This guide needs to be updated for the ESP32-S3-Zero hardware and new unified firmware. See TiltyBot_Workshop_Guide_EN.md for the current English version. Key changes:
  - Hardware: TinyPICO → Waveshare ESP32-S3-Zero
  - Wiring: GPIO1+GPIO2 for Dynamixel data, 5V, GND
  - Motor setup: separate motor_setup tool (pio run -e motor_setup -t upload)
  - Single firmware: all modes in one upload (pio run -e tiltybot -t upload)
  - SSL certs: upload via pio run -e tiltybot -t uploadfs
  - WiFi password must be 8+ characters
  - No more mode selection in platformio.ini — pick from index page
  - URL is always https://192.168.4.1
-->

ESP32-S3、Dynamixelモーター、オープンソースソフトウェアを使って、スマートフォンで操作できるロボットを作るハンズオンワークショップです。

---

## 目次

1. [事前準備](#1-事前準備)
2. [ソフトウェアセットアップ — ベースロボットの作り方](#2-ソフトウェアセットアップ--ベースロボットの作り方)
3. [ハードウェアの組立て](#3-ハードウェアの組立て)
4. [インタラクションデザイン](#4-インタラクションデザイン)

---

## 1. 事前準備

ワークショップ開始前に行う準備です。どこかのステップができなくても心配ありません。当日、対面でサポートいたします。

### 始める前の確認

- **Macをお使いの方：** OSのバージョンが **macOS Sonoma以降** であることを確認してください。
- **iPhoneをお使いの方：** iOSのバージョンが **17.3.1以降** であることを確認してください。
- ロボットの操作には **個人のスマートフォン** を使用します。企業管理のスマートフォンはセキュリティソフトウェアの制限により使用できない場合があります。

### ステップ1：Visual Studio CodeとGitのインストール

以下のリンクからダウンロードし、デフォルト設定のままインストールしてください。

- [Visual Studio Code](https://code.visualstudio.com/)
- [Git](https://git-scm.com/download/win)（Windows用）/ Macには通常プリインストールされています

### ステップ2：TiltyBotリポジトリのクローン

プロジェクトのリポジトリ（ソースコードやファイルが入ったフォルダ）をパソコンの任意の場所（デスクトップなど）にクローンします。

1. ターミナルを開きます（Windowsの場合は保存先のフォルダで右クリック →「**Git Bash Here**」を選択）。

フォルダからGit Bashを開く

2. 以下のコマンドを実行します：

```
git clone https://github.com/imandel/tiltybot.git
```

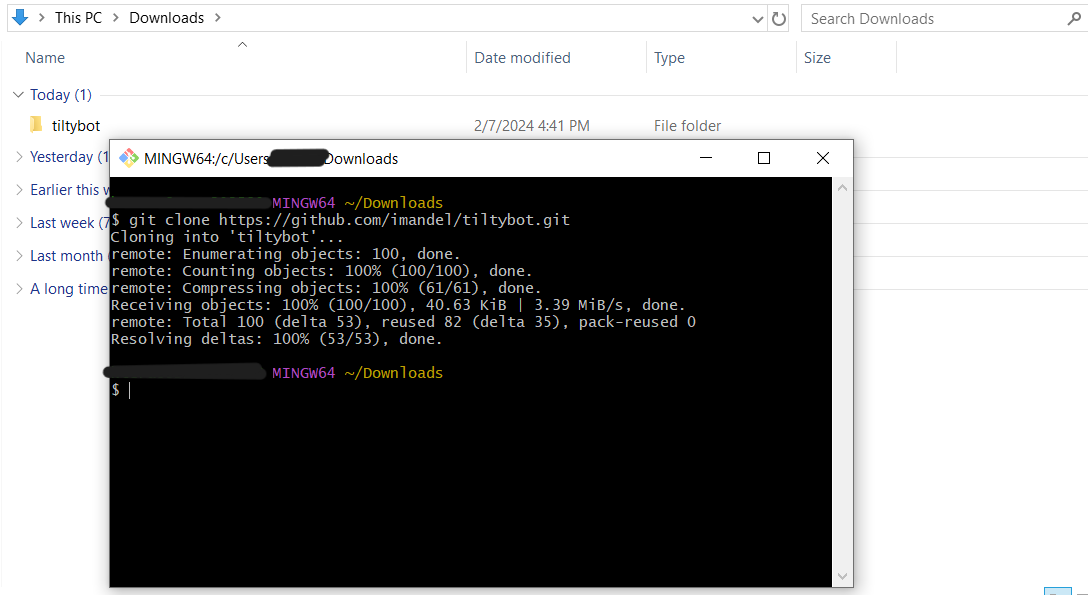
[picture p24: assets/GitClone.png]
リポジトリのクローン


### ステップ3：PlatformIOのインストール（Visual Studio Code上）

1. VS Codeで **View → Extensions** を開きます。**PlatformIO** を検索してインストールします。

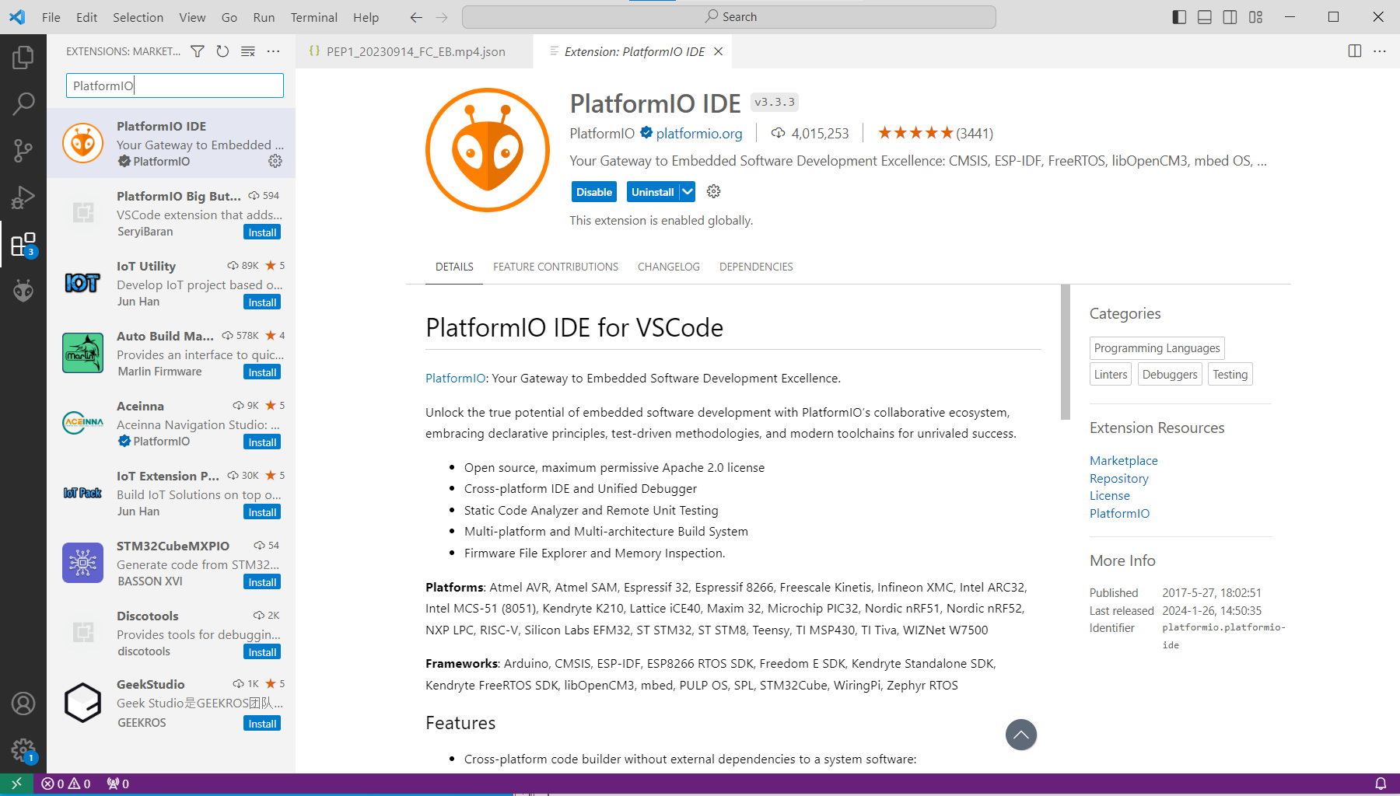
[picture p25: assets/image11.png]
PlatformIO拡張機能のインストール


2. 左サイドバーのPlatformIOアイコン（アリのマーク）アリのアイコンをクリックして初期設定を開始します。右下に「Finished」と表示されるまで待ちます。

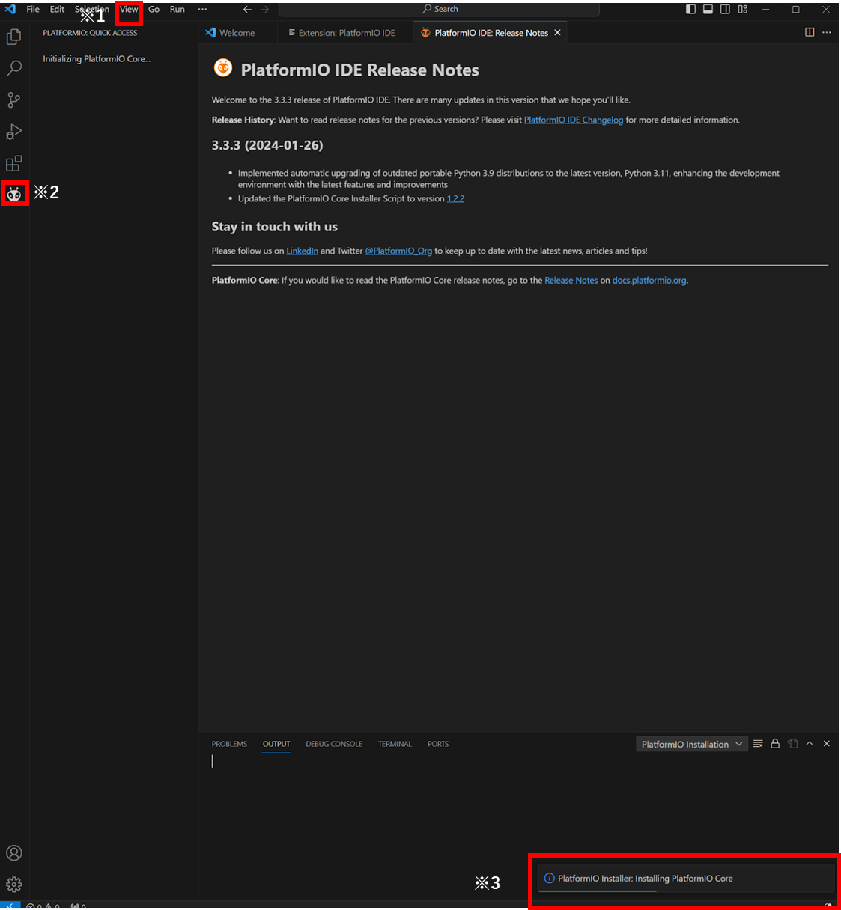
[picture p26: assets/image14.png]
PlatformIO初期設定中


3. 「**Reload Now**」と表示されたらクリックしてリロードします。

### ステップ4：プロジェクトのビルド

1. PlatformIOでTiltyBotリポジトリを開きます：アリのアイコン → **Quick Access → Open** → クローンした `tiltybot` フォルダを選択。

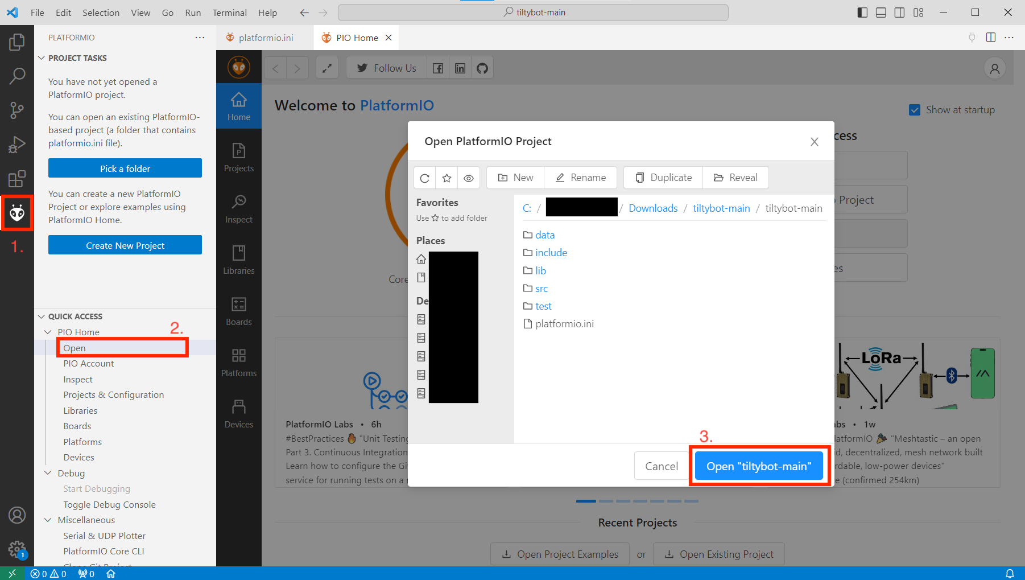
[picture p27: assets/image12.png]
PlatformIOでプロジェクトを開く


2. 左端のファイルエクスプローラーから `platformio.ini` を開きます。

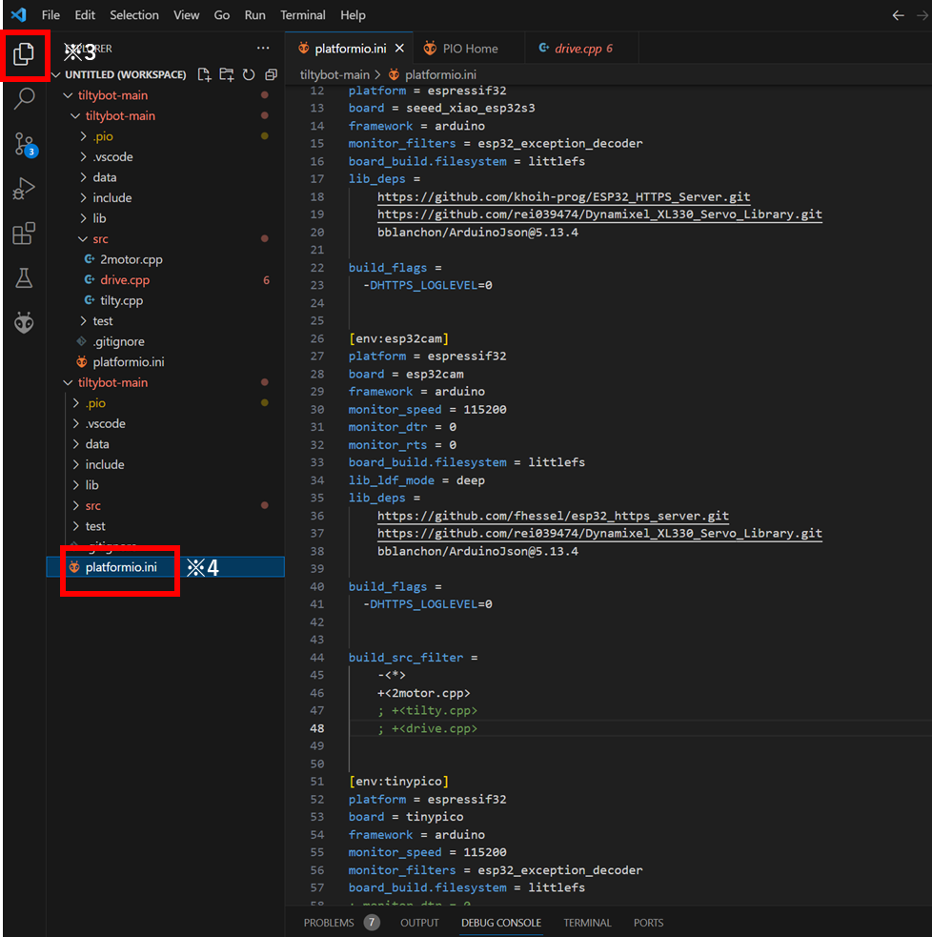
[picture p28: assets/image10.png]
platformio.iniの選択


3. 画面下部の **ビルドボタン**（チェックマーク）を押してビルドを実行します。

ビルドボタンの位置

以上で事前準備は完了です！

---

## 2. ソフトウェアセットアップ — ベースロボットの作り方

ベースロボットには3つのコントロールモードがあります：

- **ドライブモード：** 車輪を使って動き回るモバイルロボット。
- **ティルティモード：** 顔を傾けたり見回したりできるダッシュボード型ロボット。
- **2モーターモード：** 2つのモーターを0〜360°で直接制御。オリジナルロボットの設計に便利。

### 始める前に

- OS/iOSバージョンが要件を満たしていることを確認してください（事前準備セクション参照）。
- TinyPICOとDynamixelモーターをUSBでパソコンに接続してください。

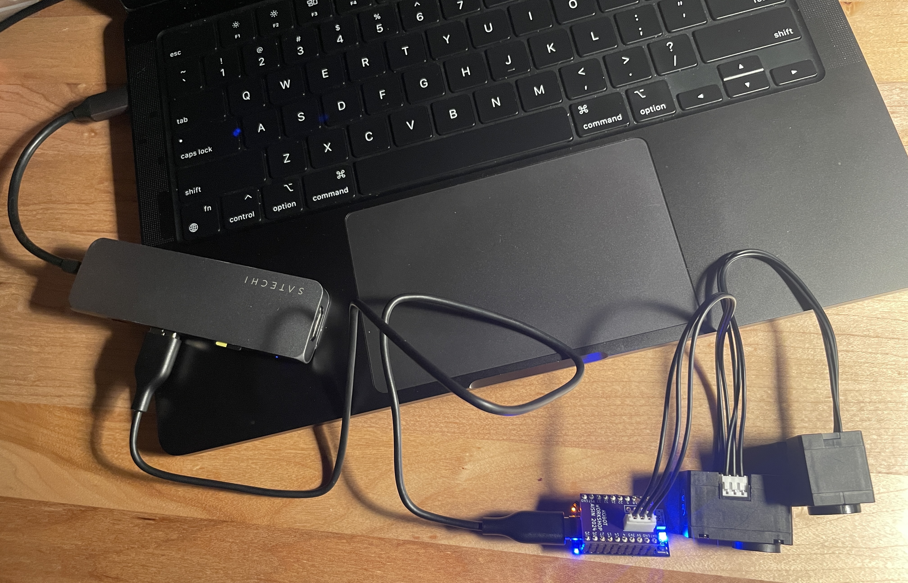
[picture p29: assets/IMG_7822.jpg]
TinyPICOとモーターをパソコンに接続


### ステップ1：コントロールモードの選択

VS Codeで `platformio.ini` を開きます。28行目付近に以下の3つのソースファイルがあります：

```
+<2motor.cpp>
+<tilty.cpp>
+<drive.cpp>
```

使用したいモードの行を有効にし、残りの2つを行頭に `;` を付けてコメントアウトします。例えば、2モーターモードを有効にする場合：

```
+<2motor.cpp>
;+<tilty.cpp>
;+<drive.cpp>
```

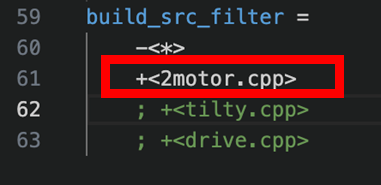
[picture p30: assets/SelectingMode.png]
platformio.iniでモードを選択


以降の手順では **2モーターモード** を使用します。他のモードに変更したい場合は、このファイルを編集して再アップロードしてください。

### ステップ2：Wi-Fi情報の設定

ロボットはローカルWi-Fiネットワークのホストになります（インターネット接続はありません）。スマートフォンでこのネットワークに接続し、ブラウザからロボットを操作します。

`network.h` を開き、SSIDとパスワードを設定してください。他の参加者と重複しないよう、自分の名前やチーム名など分かりやすい名前を推奨します。

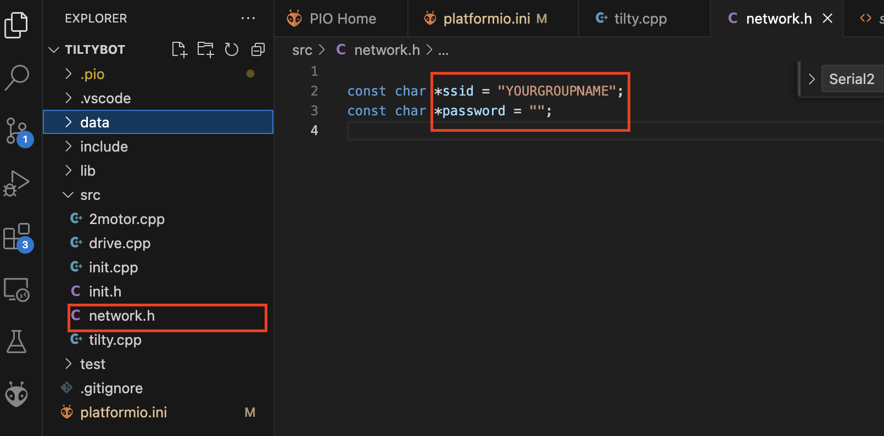
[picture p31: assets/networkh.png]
network.hの編集


### ステップ3：ファームウェアのアップロード

画面下部の **アップロードボタン**（→矢印）を押して、C++で書かれたファームウェアをTinyPICOにアップロードします。このファームウェアは、Wi-Fiネットワークのホスティング、Webサーバの起動、ロボットとブラウザ間の通信を担当します。

アップロードボタン

「SUCCESS」と表示されれば完了です：

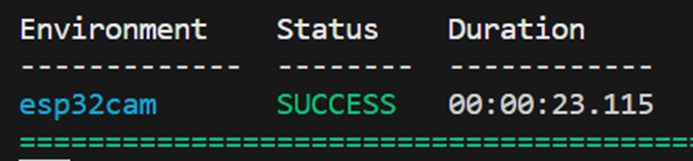
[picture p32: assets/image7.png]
アップロード成功


### ステップ4：ファイルシステムイメージのビルド

ブラウザ用のインターフェース（HTML、JavaScript、CSS）は別途フラッシュメモリにアップロードする必要があります。

**PlatformIOアリアイコン → Platform → Build Filesystem Image** をクリックします。

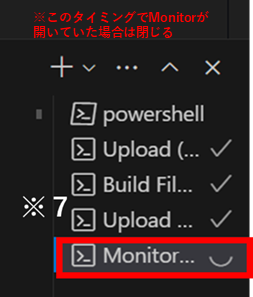
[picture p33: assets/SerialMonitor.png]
Build Filesystem Imageメニュー


「SUCCESS」と表示されれば完了です：

ビルド成功

### ステップ5：ファイルシステムイメージのアップロード

**PlatformIOアリアイコン → Platform → Upload Filesystem Image** をクリックします（OTAではありません）。

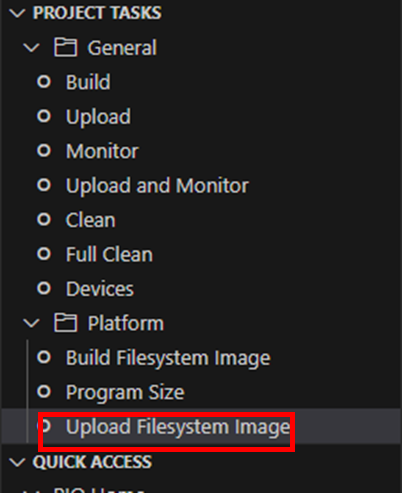
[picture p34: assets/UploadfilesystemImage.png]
Upload Filesystem Imageメニュー


**重要：** アップロード前にシリアルモニターが閉じていることを確認してください。開いている場合は、下部のMonitorタブにカーソルを合わせてゴミ箱アイコンをクリックして閉じてからアップロードしてください。

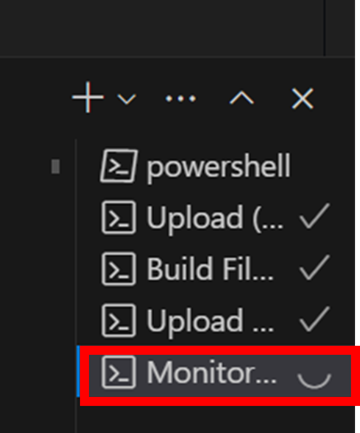
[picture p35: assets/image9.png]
アップロード前にシリアルモニターを閉じる


### ステップ6：スマートフォンとロボットの接続

1. VS Code下部の **シリアルモニター**（コンセントのアイコン）を開き、IPアドレスを確認します。表示されない場合はTinyPICOの **リセットボタン** を押してください。

シリアルモニターにIPアドレスが表示

リセットボタンはデバイスの表面にあります：

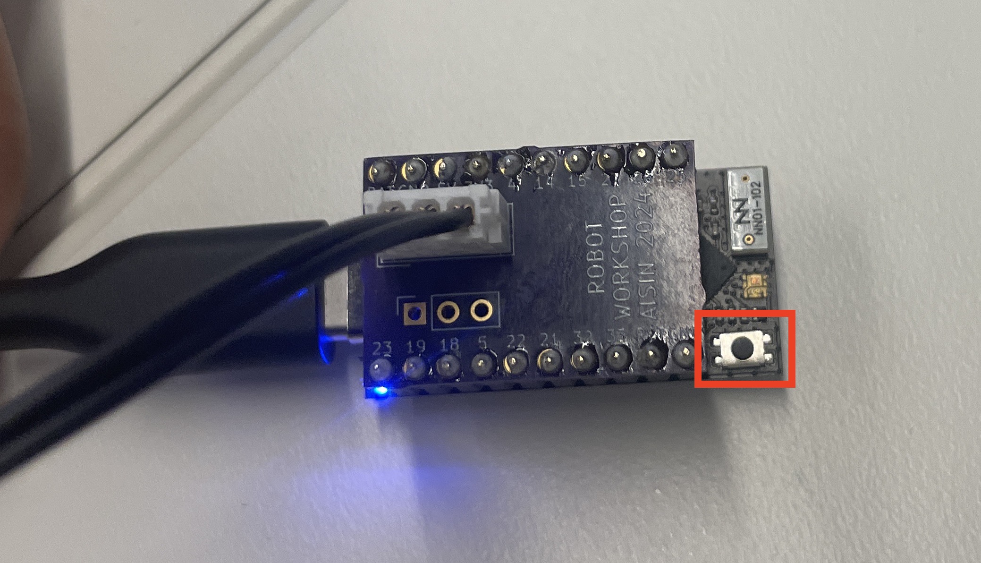
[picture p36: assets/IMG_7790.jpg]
リセットボタンの位置


2. スマートフォンのWi-Fi設定で、ステップ2で設定したネットワークに接続します。「インターネット接続なし」等の警告は無視してください。プライバシーに関する警告も表示される場合がありますが、そのまま接続してください。

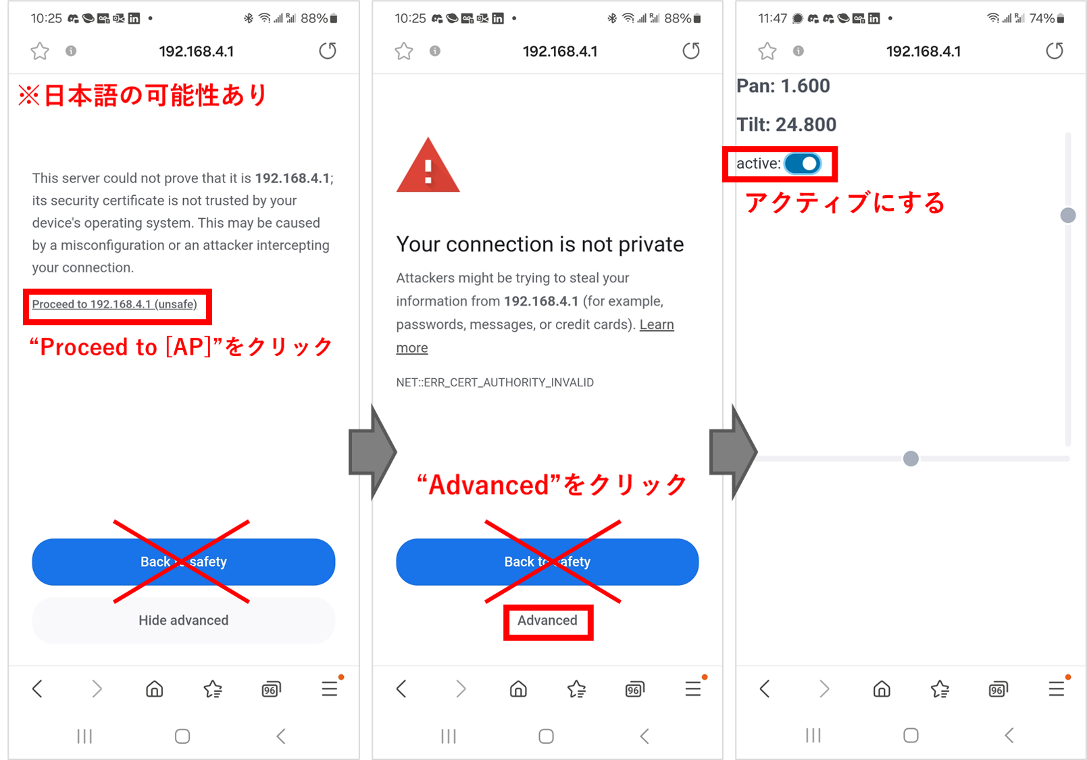
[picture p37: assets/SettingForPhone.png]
スマートフォンのWi-Fiと証明書の設定


3. スマートフォンのブラウザで、シリアルモニターに表示されたURL（例：`https://192.168.X.X/2motor.html`）にアクセスします。

4. コントロールパネルの **Activate** を押し、画面上のスライダーを操作します。シリアルモニターに数値が表示されれば接続成功です。

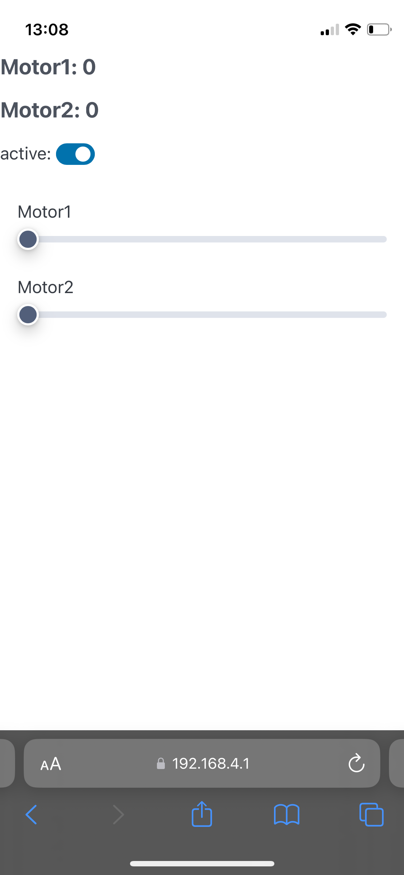
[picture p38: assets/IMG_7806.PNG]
2モーターモードのスマートフォン操作画面


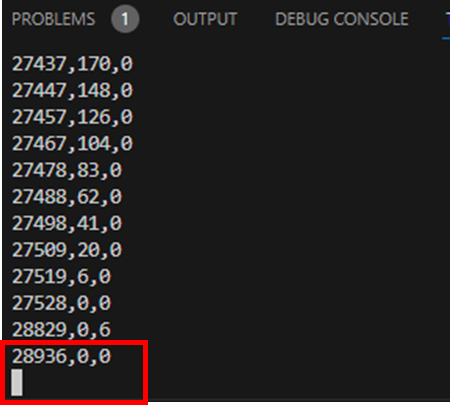
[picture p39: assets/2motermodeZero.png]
シリアルモニターにモーター値が表示


**ヒント：** スマートフォンのモバイルデータ通信をOFFにすると、通信が自動的に切り替わるのを防げます。VPNに接続している場合は切断してからアクセスしてください。

**重要：** モーターを取り外す前に、両方のモーターのポジションを必ず **0** に設定してください。手でモーターの位置を無理に変えないでください。ティルティロボットの組立て時に特に重要です。

### ステップ7：オーディオ機能

ロボットはBluetoothスピーカーを使って音を出すこともできます。

**Bluetoothスピーカーの接続：**

1. Bluetoothスピーカーの電源を入れます。

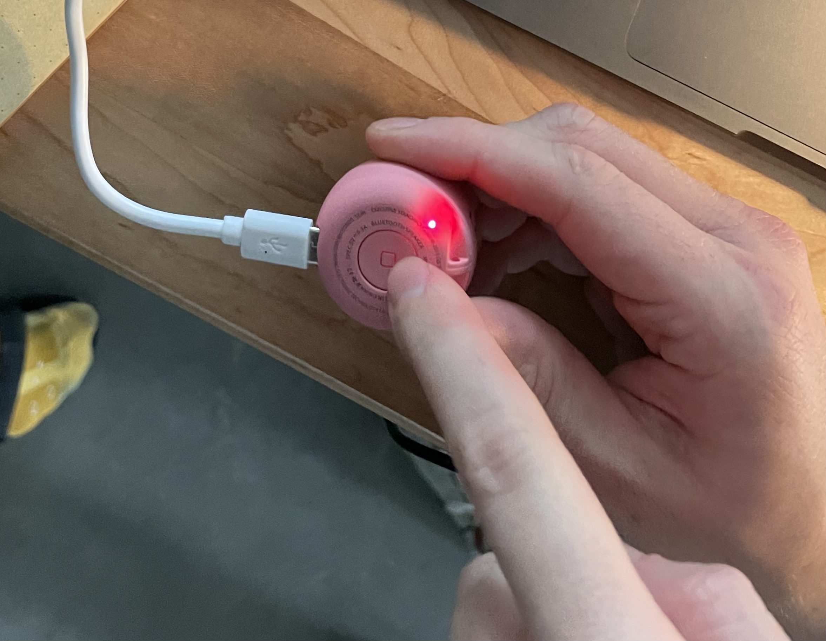
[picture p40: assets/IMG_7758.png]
Bluetoothスピーカーの電源ボタン


2. スマートフォンのBluetooth設定からスピーカーに接続します。

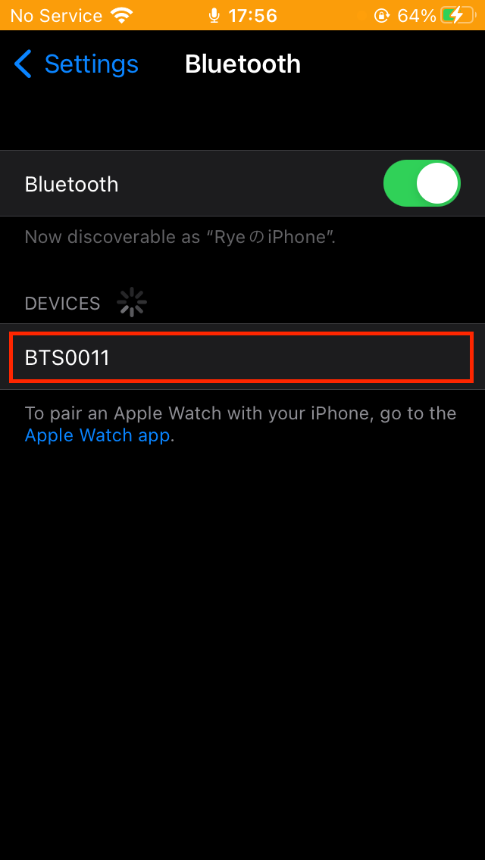
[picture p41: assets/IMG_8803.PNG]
スマートフォンのBluetoothペアリング


**録音と再生：**

1. スマートフォンのブラウザで `https://{IPアドレス}/sounds.html` にアクセスします。マイクへのアクセス許可を求められた場合は許可してください。

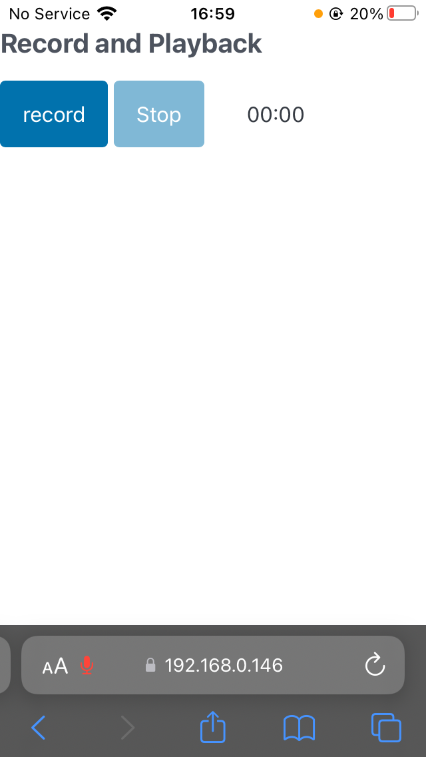
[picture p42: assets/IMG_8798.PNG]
サウンドページとマイク許可

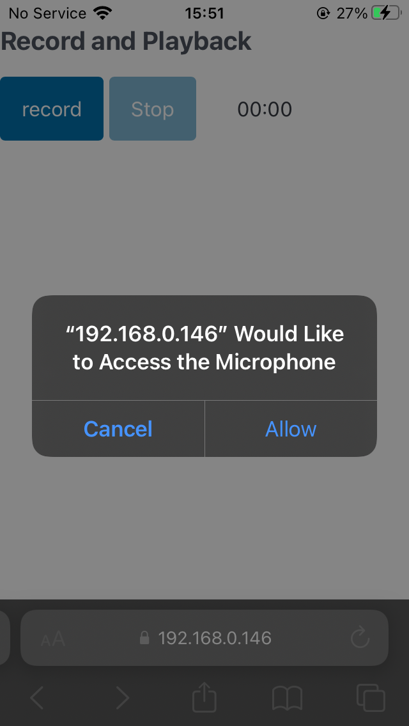
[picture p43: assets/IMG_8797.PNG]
マイクアクセスの許可プロンプト


2. **Record** ボタンを押して録音を開始します。タイマーで録音時間を確認できます。**Stop** ボタンを押して録音を終了します。

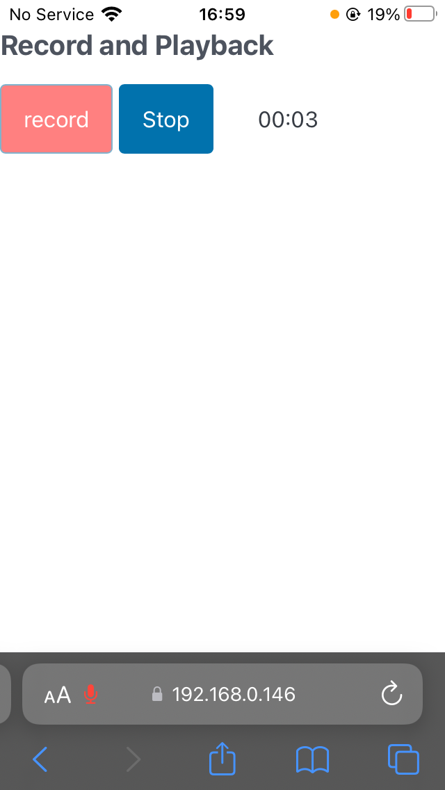
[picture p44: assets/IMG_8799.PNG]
録音中


3. ポップアップで任意の名前を入力し「OK」を押して保存します。

4. **Play** ボタンを押して録音を再生します。

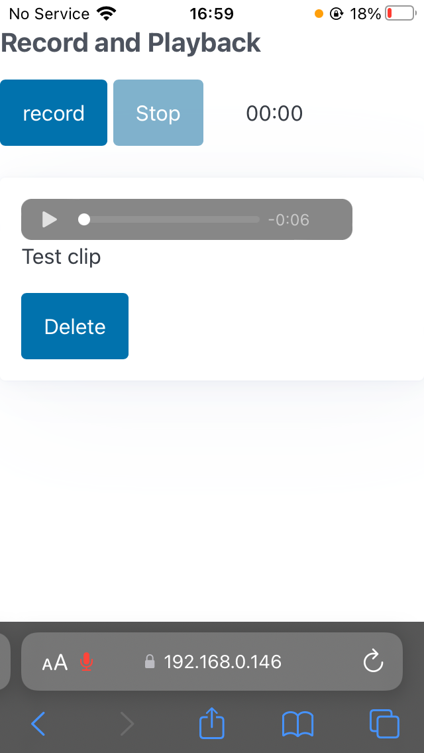
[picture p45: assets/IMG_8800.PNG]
再生コントロール


**注意：** コントロール画面をリロードすると録音したデータが消えてしまいます。

---

## 3. ハードウェアの組立て

以下の2種類のロボットから選んで組み立てます：

| ドライブロボット | ティルティロボット |
|---|---|
| 車輪で移動するモバイルロボット | 傾き・パン動作ができるダッシュボード型ロボット |

### ベースの組立て

コア部品（TinyPICO＋Dynamixelモーター）を下の写真のように組み立て、USB A-Cケーブルでパソコンに接続します。

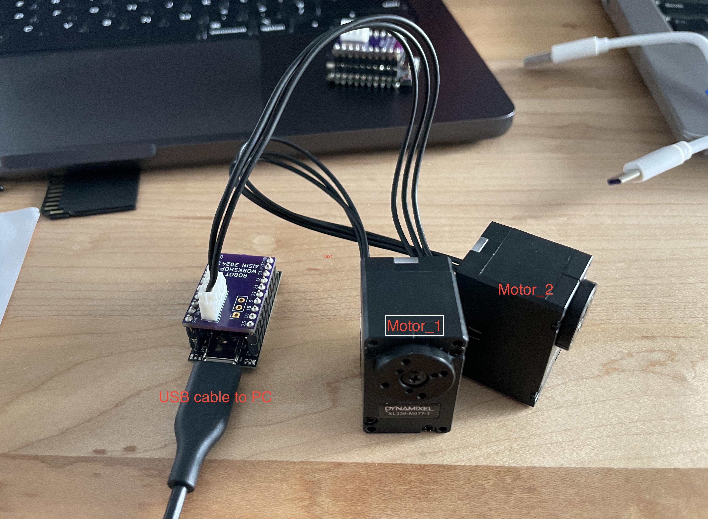
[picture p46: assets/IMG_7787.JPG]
ベースロボットの組立て


### ドライブロボットの組立て

1. **軸の取り付け：** ネジを使って白い軸パーツを各モーターに取り付けます。

モーターに軸パーツを取り付け
軸用のネジ

2. **タイヤの取り付け：** 軸をタイヤに差し込みます。

タイヤを軸に取り付け

3. **台の作成：** ダンボールなどの素材を使って、モーターを取り付ける台を作ります。

ダンボールの台

4. **部品の配置：** 2つのDynamixelモーターと360度タイヤを台に取り付けます。三角形の配置になるようバランスを取ってください。

モーターとローラーボールの配置
完成したドライブロボットのベース

5. **ドライブモードのアップロード：** `platformio.ini` を編集して `+<drive.cpp>` を有効にし、他をコメントアウトします。ファームウェアをアップロードします。

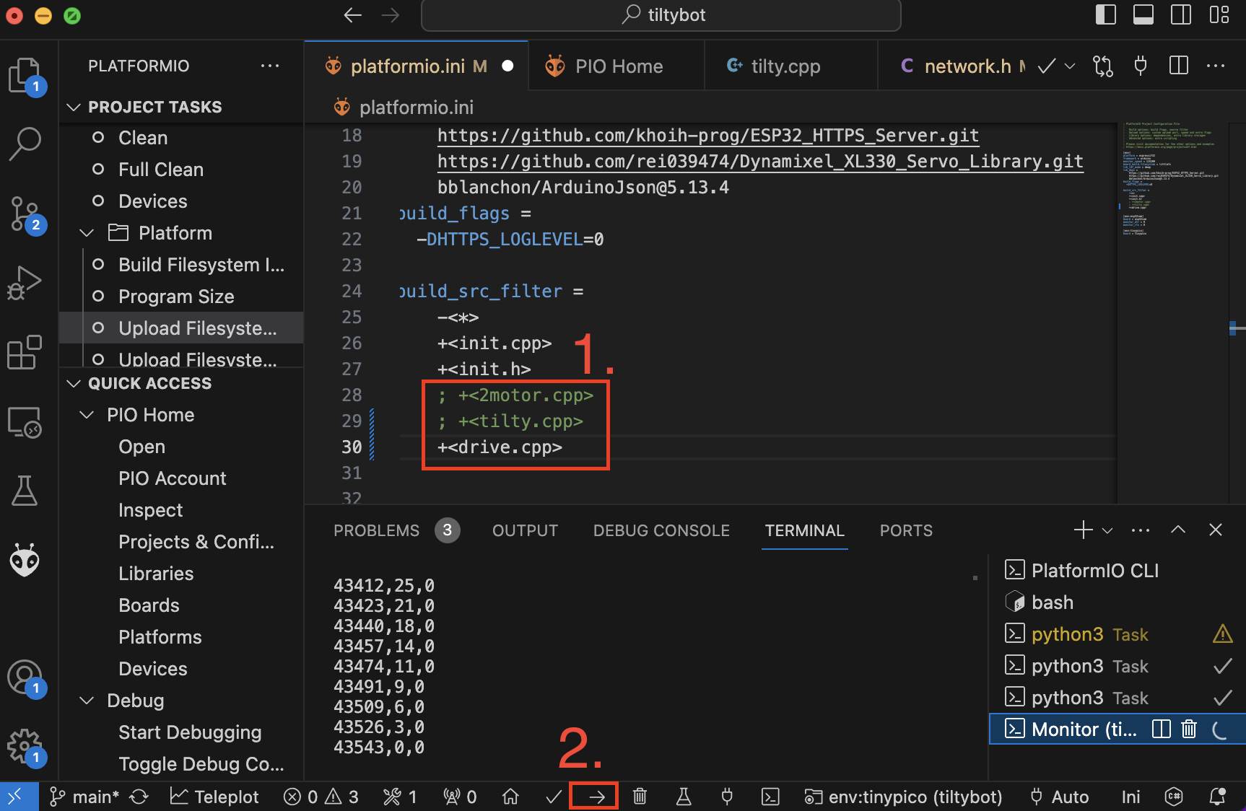
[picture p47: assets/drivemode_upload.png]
ドライブモードのplatformio.iniとアップロード


**注意：** モードによってアクセスするURLのパスが変わります（`/drive.html`、`/2motor.html`、`/tilty.html`）：

モードごとのURL変更

6. **スマートフォンの接続：** ロボットのWi-Fiネットワークに接続し、シリアルモニターに表示されたURL（例：`https://192.168.X.X/drive.html`）にアクセスします。

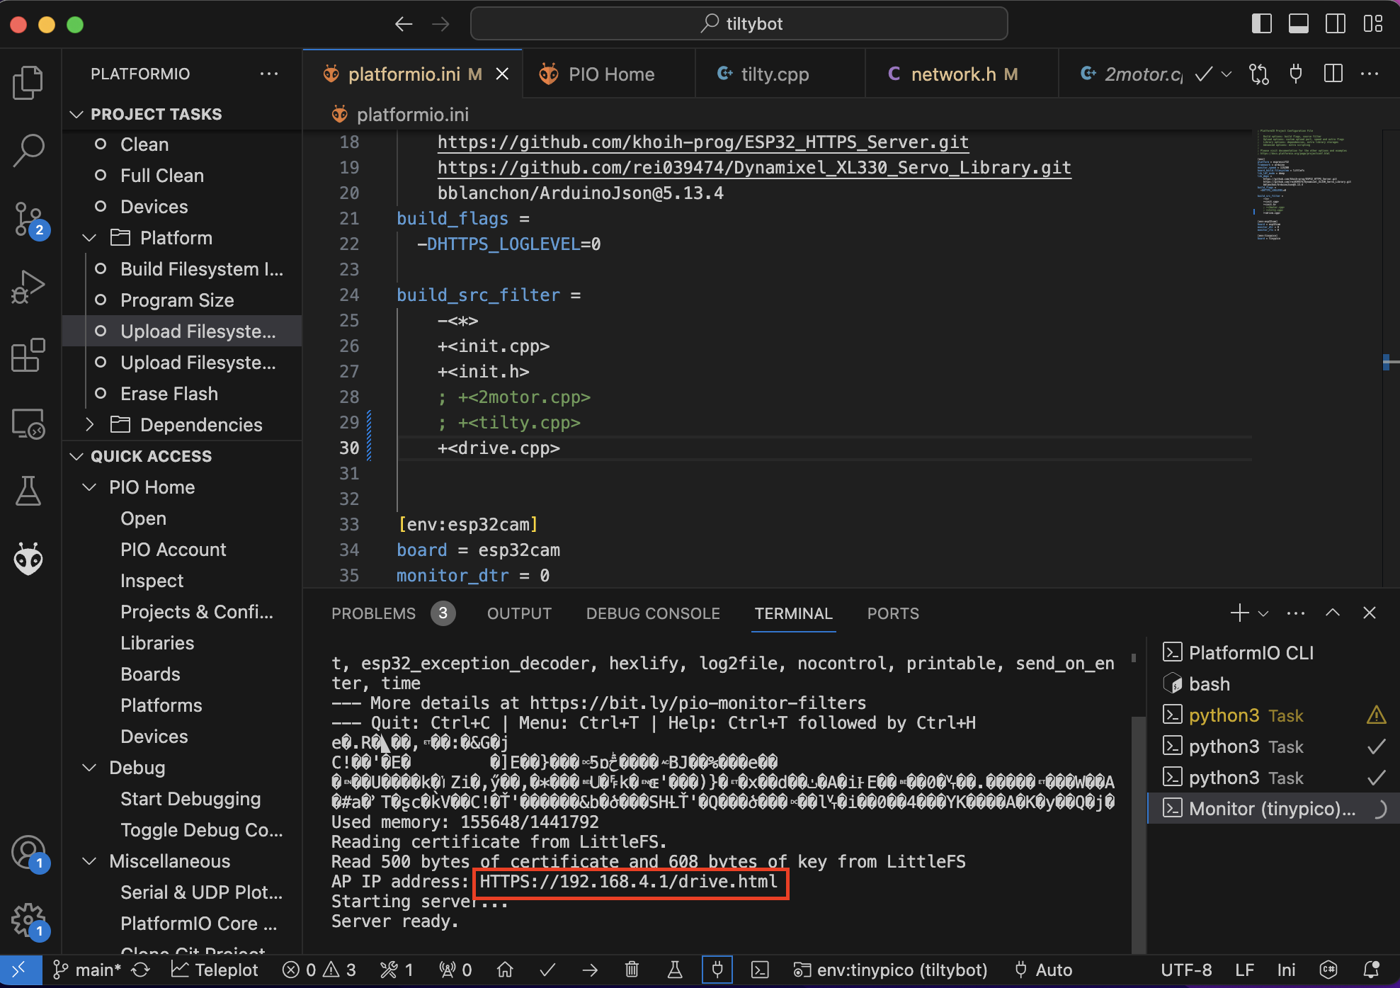
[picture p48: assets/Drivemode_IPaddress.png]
ドライブモードのIPアドレス表示


7. **操作：** Activateを押して、画面上のジョイスティックでロボットを操作します。

ドライブモードの動作

**前提条件：** 組み立て前に2モーターモードで両方のモーターをポジション0に設定してください。

1. **モーターをゼロに設定：** 2モーターモードのコントロールページに接続し、両方のモーターポジションを0にします。

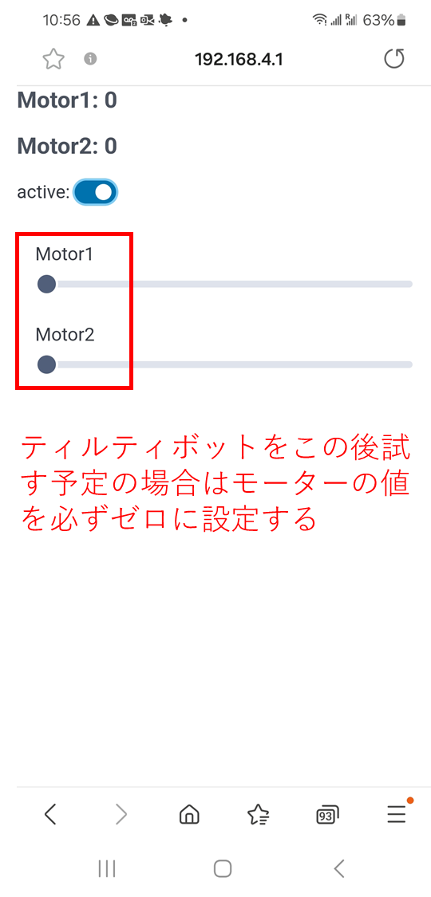
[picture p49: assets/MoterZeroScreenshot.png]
スマートフォンでモーターをゼロに設定

シリアルモニターでゼロ確認

2. **ヘッドの取り付け：** 短いネジを使って、ヒンジブラケットを **モーター1** に取り付けます。ポジション0の状態で「ヘッド」が前方を向くようにします。

モーター1にヘッドを取り付け
ブラケット用のネジ

3. **アイドラーの取り付け：** **モーター2** にアイドラーとアイドラーキャップのみを取り付けます。

アイドラー用のネジ

4. **組み合わせ：** ヘッド/ヒンジアセンブリをモーター2に正しい向きで取り付けます（モーター2上部のLEDが手前を向くようにします）。**ホイールを手で回転させないでください！**

正しい組立て向き

5. **ティルティモードのアップロード：** `platformio.ini` を編集して `+<tilty.cpp>` を有効にし、他をコメントアウトします。ファームウェアをアップロードします。

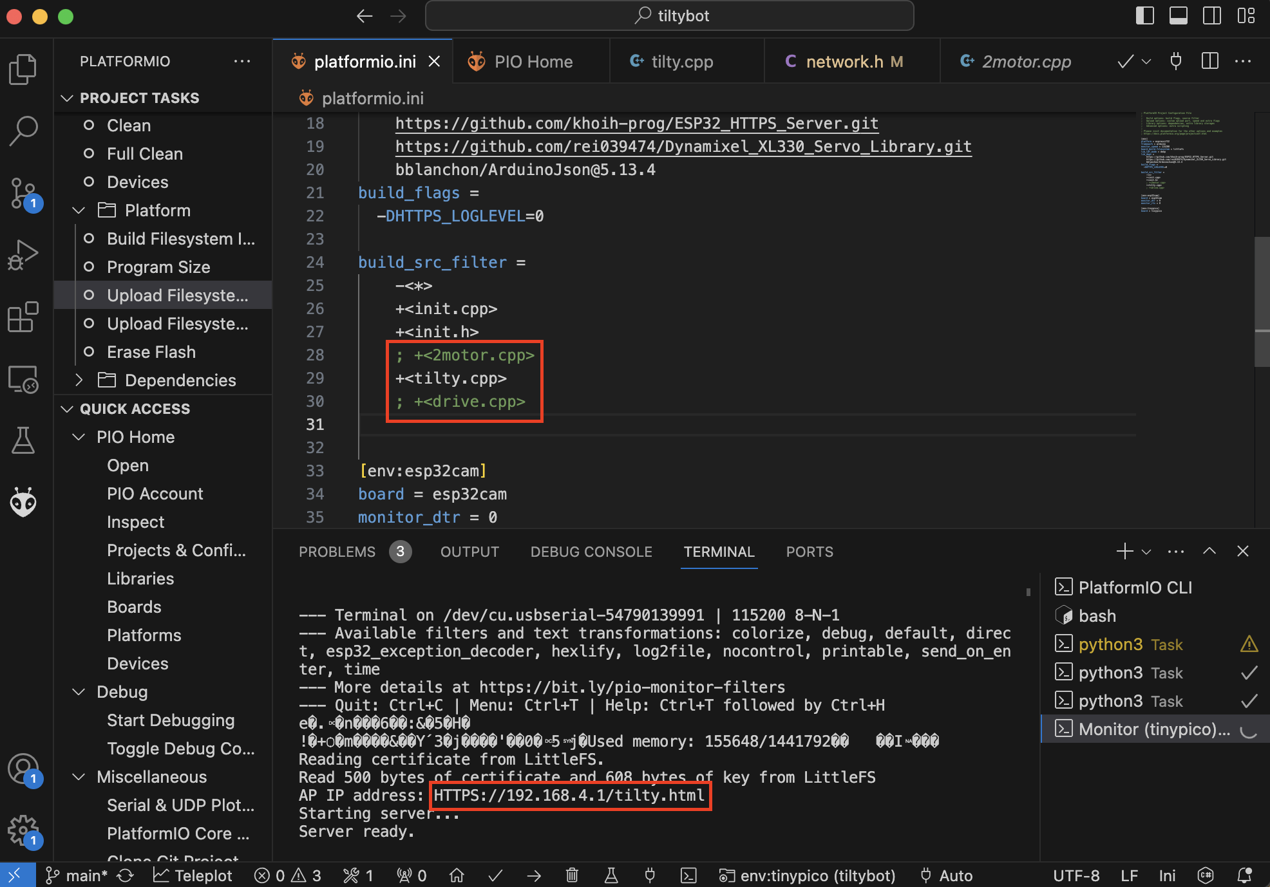
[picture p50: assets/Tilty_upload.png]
ティルティモードのアップロード


6. **スマートフォンの接続：** Wi-Fiネットワークに接続し、シリアルモニターに表示されたURLにアクセスします。

7. **操作：** Activateを押して、画面上のコントロールまたはスマートフォンのジャイロスコープでロボットを傾けたりパンしたりできます。

ティルティモードの動作

ロボットが完成したら、人とロボットのインタラクション（やり取り）について考えます。このセクションでは、デザイン思考のエクササイズを行います。

### 全体の流れ

A. [プランニング](#part-a-プランニング)
B. [インタラクションを演じる](#part-b-インタラクションを演じる)
C. [見た目をデザインする](#part-c-見た目をデザインする)
D. [デバイスを操作する](#part-d-デバイスを操作する)
E. [撮影する](#part-e-撮影する)

### Part A: プランニング

ロボットと人のインタラクションを設計するために、以下の4つの要素を考えてみてください。

1. **設定（Setting）：** そのインタラクションはどこで、いつ起こりますか？（例：キッチン、病院、屋外など）
2. **プレイヤー（Players）：** 誰が関わりますか？メインのユーザーだけでなく、周囲にいる人全員を考えてください。悪いデザインの例として、Amazon Alexaがルームメイトや子供の存在を十分に考慮せず設計されたことで、意図しない注文が行われるという問題が起きたケースがあります。
3. **アクティビティ（Activity）：** プレイヤーとロボットの間で何が起こりますか？
4. **ゴール（Goals）：** 各プレイヤーの目標は何ですか？（例：通知を受け取る、空間を移動する、感情を表現するなど）

設定・プレイヤー・アクティビティ・ゴールを書き出してください。

### Part B: インタラクションを演じる

プランしたシナリオをロボットなしで実際に演じてみてください。デバイスの役割は人が代わりに演じます。

演じた後に振り返りましょう：

- 紙の上では良さそうだったのに、実際にはうまくいかなかったことはありますか？
- 演じてみて新しいアイデアや発見はありましたか？

### Part C: 見た目をデザインする

次に、ロボットの見た目を考えます。以下の点を検討してください：

- 環境：オーバーヒートの可能性は？水濡れのリスクは？緊急時に目立つ色が必要？
- ユーザー：どのような形状やデザインが、使う人にとって自然で親しみやすいですか？

紙にスケッチを描き、ダンボールやテープなどの素材を使って実際にプロトタイプを作ってみましょう。

### Part D: デバイスを操作する

シナリオ通りにロボットを動かす練習をします。一人がコントローラーを操作し、もう一人がユーザーとしてロボットとやり取りします。

### Part E: 撮影する

プロトタイプのインタラクションを動画に撮影してください。設定、プレイヤー、ロボットの動きを含むシナリオ全体を記録します。この動画はアイデアのプレゼンテーションやさらなる改善に活用できます。

---

## 参考リンク

- **TiltyBotリポジトリ：** [https://github.com/imandel/tiltybot](https://github.com/imandel/tiltybot)
- **Visual Studio Code：** [https://code.visualstudio.com/](https://code.visualstudio.com/)
- **PlatformIO：** [https://platformio.org/](https://platformio.org/)
- **Git：** [https://git-scm.com/](https://git-scm.com/)

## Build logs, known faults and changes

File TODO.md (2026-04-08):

# TiltyBot — TODO

## Features

- [ ] **Sync Write for position modes** — tilty, puppet following, and 2-motor use sequential `setJointPosition` calls with ~3ms inter-motor delay. Use Dynamixel Sync Write (instruction 0x83, already implemented as `syncWrite()` for drive mode) to write both motors in one packet. Register 116 = Goal Position, 4 bytes. `syncWrite(116, 4, MOTOR1, m1, MOTOR2, m2)`.

- [ ] **Captive portal** — Auto-open control page when joining WiFi (DNS redirect). Best workshop UX — no URL typing needed.
- [ ] **mDNS** — Advertise as `tiltybot.local` for easier access (works on Apple devices, spotty on Android).
- [ ] **Tilty gain multiplier** — Small phone movements should map to larger robot range. Start with 2x, tune to feel. Currently 1:1.
- [ ] **Re-center button** — Recapture gyro reference quaternion without toggling gyro off/on.
- [ ] **Custom tilt/pan position limits UI** — Calibrate page currently sets symmetric ±90°. Add per-axis limit setting based on body clearance measurement.
- [ ] **iOS tilty support** — Deferred. Would need DeviceOrientationEvent fallback with gimbal lock mitigation.

## Hardware

- [ ] **Wiring diagram** — Create a proper diagram showing ESP32-S3-Zero to Dynamixel connections.

## Documentation

- [ ] **Workshop guide screenshots** — Update images marked with `<!-- TODO -->`:
  - Screenshot of index page on phone
  - Photo of wiring close-up
  - Screenshot of 2-motor mode at 0 position
- [ ] **Japanese workshop guide** — Translate updates from EN guide to `TiltyBot_Workshop_Guide_JP.md`.

## Done

- [x] Move HTML to LittleFS — all pages served from `data/`
- [x] Tilty gyro mode — RelativeOrientationSensor with delta quaternion, zero gimbal lock
- [x] Puppet mode — ESP-NOW pairing with emoji grid, degree-based packets
- [x] Calibration page — homing offset + position limits via web UI
- [x] Sound page — TTS, synthesized soundboard, recording, file upload, saved sounds (IndexedDB)
- [x] Half-duplex echo fix — custom readMotorPosition() skips TX echo bytes
- [x] WiFi AP-only mode — eliminates STA scanning latency
- [x] BOT_SSID build flag — set SSID at compile time

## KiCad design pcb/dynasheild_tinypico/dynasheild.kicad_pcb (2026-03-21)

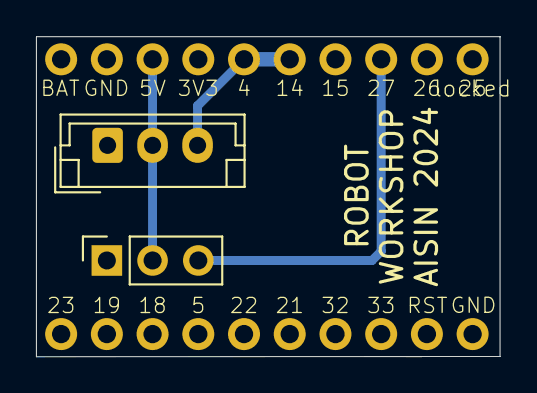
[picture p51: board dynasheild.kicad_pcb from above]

Board: 2 copper layers, 25.8 x 17.8 mm, 4 parts (0 on the bottom side), 4 nets.

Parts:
J1: B3B-EH-ALFSN; JST_EH_B3B-EH-A_1x03_P2.50mm_Vertical
J2: Conn_01x03_Pin; PinSocket_1x03_P2.54mm_Vertical
LEFT0: TINYPICO_HEADER_10NO_SILK_PTH_FEMALE; 1X10_NO_SILK
RIGHT0: TINYPICO_HEADER_10NO_SILK_PTH_FEMALE; 1X10_NO_SILK

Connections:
/GND: J1.1, J2.1, LEFT0.2, RIGHT0.10
/GPIO14: J1.3, LEFT0.5, LEFT0.6
/GPIO27: J2.3, LEFT0.8
/USB: J1.2, J2.2, LEFT0.3

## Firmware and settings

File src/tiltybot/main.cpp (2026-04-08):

/*
 * TiltyBot — Unified Firmware
 *
 * Single firmware serving all control modes:
 *   - Drive: differential drive with virtual joystick
 *   - Tilty: pan/tilt head via phone gyroscope or sliders
 *   - 2-Motor: direct position control (0-360°)
 *
 * Switch between modes via the index page at https://192.168.4.1
 * Motor control mode switches automatically on WebSocket connect.
 *
 * Hardware: Waveshare ESP32-S3-Zero + 2x Dynamixel XL330
 * Flash with: pio run -e tiltybot -t upload
 */

#include <Arduino.h>
#include <WiFi.h>
#include <esp_wifi.h>
#include <esp_now.h>
#include <LittleFS.h>
#include <ArduinoJson.h>
#include <PsychicHttp.h>
#include <PsychicHttpsServer.h>
#include "XL330.h"
#include "dxl_pro.h"  // for update_crc

// ---- Pin config (Waveshare ESP32-S3-Zero) ----
#define RXD2 2
#define TXD2 1
#define RGB_LED 21
#define DRIVE_MODE 16
#define POSITION_MODE 3
#define BROADCAST 254
#define MOTOR1 1
#define MOTOR2 2

// ---- WiFi config ----
#ifndef BOT_SSID
#define BOT_SSID "YOURGROUPNAME"
#endif
const char *ssid = BOT_SSID;
const char *password = "12345678";

// ---- Globals ----
PsychicHttpsServer server;
PsychicHttpServer httpRedirect;
PsychicWebSocketHandler driveWs;
PsychicWebSocketHandler tiltyWs;
PsychicWebSocketHandler twoMotorWs;
XL330 robot;
String serverCert;
String serverKey;
int prevM1 = 0;
int prevM2 = 0;
int currentMode = -1;
volatile int targetM1 = 0;
volatile int targetM2 = 0;
int pendingMode = -1;
volatile bool newData = false;
uint32_t driveFrameCount = 0;
uint32_t driveLastLog = 0;
int lastJoyX = 0, lastJoyY = 0;
volatile uint32_t driveLastFrame = 0; // watchdog: ms of last received drive frame
#define DRIVE_WATCHDOG_MS 300         // stop motors if no frame for this long
bool driveWasMoving = false;          // for transition logging
uint32_t driveZerosSent = 0;          // count consecutive zero writes
volatile float lastBVal = 0, lastGVal = 0;

volatile uint32_t wsFrameCount = 0; // frames received by callback
volatile uint32_t lastSeqNum = 0;   // last sequence number from client
uint32_t loopProcessCount = 0;      // frames processed by main loop
unsigned long lastStatsTime = 0;

// ---- Calibration config ----
// Position limits relative to home (2048 after homing offset)
// ±1024 from center = ±90 degrees range
#define CALIB_CENTER 2048
#define CALIB_MIN    1024
#define CALIB_MAX    3072

// Read position with echo-skip (half-duplex bus echoes TX on RX)
int32_t readMotorPosition(int id) {
    while (Serial2.available()) Serial2.read();
    delay(10);
    int sent = robot.RXsendPacket(id, 132, 4); // 132 = Present Position
    Serial2.flush();
    delay(20);
    // Skip TX echo
    unsigned long start = millis();
    int skipped = 0;
    while (skipped < sent && millis() - start < 200) {
        if (Serial2.available()) { Serial2.read(); skipped++; }
    }
    // Parse response
    unsigned char buffer[64];
    if (robot.readPacket(buffer, 64) > 0) {
        XL330::Packet p(buffer, 64);
        if (p.isValid() && p.getParameterCount() >= 3 && p.getInstruction() == 0x55) {
            return (p.getParameter(1)) |
                   (p.getParameter(2) << 8) |
                   (p.getParameter(3) << 16) |
                   (p.getParameter(4) << 24);
        }
    }
    return -1;
}

// ---- Puppet mode ----
enum PuppetState { PUPPET_IDLE, PUPPET_CONTROLLING, PUPPET_FOLLOWING };
volatile PuppetState puppetState = PUPPET_IDLE;
uint8_t puppetPairId = 0;
unsigned long lastPuppetRx = 0;

struct __attribute__((packed)) PuppetPacket {
    uint8_t pairId;
    float tilt;  // degrees from center
    float pan;   // degrees from center
};

// ESP-NOW receive callback
volatile unsigned long puppetRxCount = 0;
void onEspNowRecv(const esp_now_recv_info_t *info, const uint8_t *data, int len) {
    if (puppetState != PUPPET_FOLLOWING) {
        if (Serial) Serial.printf("ESP-NOW rx DROPPED: len=%d state=%d\n", len, puppetState);
        return;
    }
    if (len != sizeof(PuppetPacket)) return;
    PuppetPacket *pkt = (PuppetPacket *)data;
    if (pkt->pairId != puppetPairId) {
        if (Serial) Serial.printf("ESP-NOW rx WRONG PAIR: got=%d want=%d\n", pkt->pairId, puppetPairId);
        return;
    }
    // Convert degrees back to motor positions using OUR calibration
    targetM1 = constrain(CALIB_CENTER + int(pkt->tilt / 0.088f), CALIB_MIN, CALIB_MAX);
    targetM2 = constrain(CALIB_CENTER + int(pkt->pan / 0.088f), CALIB_MIN, CALIB_MAX);
    newData = true;
    lastPuppetRx = millis();
    puppetRxCount++;
}

// Sync Write: write to the same register on both motors in a single packet.
// Both motors receive and execute simultaneously — no inter-motor delay.
// addr: register start address, len: bytes per motor (2 or 4)
void syncWrite(int addr, int len, int id1, int val1, int id2, int val2) {
    // Sync Write packet: [FF FF FD 00] [FE] [lenL lenH] [83] [addrL addrH] [lenL lenH] [id1 data...] [id2 data...] [crcL crcH]
    // Parameter size: 4 (addr+datalen) + 2*(1+len) for two motors
    int paramSize = 4 + 2 * (1 + len);
    int pktLen = 3 + paramSize; // instruction + params + crc
    int totalSize = 7 + pktLen;  // header(4) + id(1) + length(2) + pktLen
    uint8_t buf[24]; // max needed: 22 for 4-byte data
    buf[0] = 0xFF; buf[1] = 0xFF; buf[2] = 0xFD; buf[3] = 0x00;
    buf[4] = 0xFE; // broadcast ID
    buf[5] = pktLen & 0xFF; buf[6] = (pktLen >> 8) & 0xFF;
    buf[7] = 0x83; // Sync Write instruction
    buf[8] = addr & 0xFF; buf[9] = (addr >> 8) & 0xFF;
    buf[10] = len & 0xFF; buf[11] = (len >> 8) & 0xFF;
    // Motor 1
    int idx = 12;
    buf[idx++] = id1;
    for (int i = 0; i < len; i++) buf[idx++] = (val1 >> (8 * i)) & 0xFF;
    // Motor 2
    buf[idx++] = id2;
    for (int i = 0; i < len; i++) buf[idx++] = (val2 >> (8 * i)) & 0xFF;
    // CRC
    unsigned short crc = update_crc(0, buf, idx);
    buf[idx++] = crc & 0xFF;
    buf[idx++] = (crc >> 8) & 0xFF;
    Serial2.write(buf, idx);
    Serial2.flush();
}

void setMotorMode(int mode) {
    // Stop any motion first
    if (currentMode == DRIVE_MODE) {
        robot.setJointSpeed(MOTOR1, 0);
        robot.setJointSpeed(MOTOR2, 0);
        delay(10);
    }
    robot.TorqueOFF(BROADCAST);
    delay(50);
    robot.setControlMode(BROADCAST, mode);
    delay(50);
    robot.TorqueON(BROADCAST);
    delay(50);
    prevM1 = 0;
    prevM2 = 0;
    currentMode = mode;
    Serial.printf("Motor mode -> %s\n", mode == DRIVE_MODE ? "DRIVE" : "POSITION");
}

// Helper to serve a LittleFS file with correct content type
esp_err_t serveFile(PsychicRequest *request, PsychicResponse *response, const char *path, const char *contentType) {
    File f = LittleFS.open(path);
    if (!f) {
        return response->send(404, "text/plain", "File not found");
    }
    String content = f.readString();
    f.close();
    response->addHeader("Cache-Control", "no-cache, no-store, must-revalidate");
    return response->send(200, contentType, content.c_str());
}

void setup() {
    Serial.begin(115200);
    delay(2000);
    Serial.println("\n=== TiltyBot ===");

    Serial2.begin(115200, SERIAL_8N1, RXD2, TXD2);

    // LittleFS + SSL certs
    if (!LittleFS.begin()) {
        Serial.println("LittleFS mount failed!");
    } else {
        File certFile = LittleFS.open("/server.crt");
        File keyFile = LittleFS.open("/server.key");
        if (certFile && keyFile) {
            serverCert = certFile.readString();
            serverKey = keyFile.readString();
            certFile.close();
            keyFile.close();
            server.setCertificate(serverCert.c_str(), serverKey.c_str());
            Serial.println("SSL certs loaded");
        } else {
            Serial.println("SSL cert/key not found!");
        }
    }

    // WiFi AP only (ESP-NOW works in AP mode too)
    // AP_STA causes STA-side scanning that creates multi-second gaps
    WiFi.mode(WIFI_AP);
    WiFi.softAP(ssid, password);
    delay(500);
    esp_wifi_set_ps(WIFI_PS_NONE);
    Serial.printf("AP IP: %s\n", WiFi.softAPIP().toString().c_str());

    // ESP-NOW init
    if (esp_now_init() != ESP_OK) {
        Serial.println("ESP-NOW init failed");
    } else {
        esp_now_register_recv_cb(onEspNowRecv);
        // Add broadcast peer
        esp_now_peer_info_t peer = {};
        memset(peer.peer_addr, 0xFF, 6);
        peer.channel = 0;
        peer.encrypt = false;
        peer.ifidx = WIFI_IF_AP;
        esp_now_add_peer(&peer);
        Serial.println("ESP-NOW ready");
    }

    // --- Drive WebSocket ---
    driveWs.onOpen([](PsychicWebSocketClient *client) {
        Serial.println("Drive client connected");
        puppetState = PUPPET_IDLE;
        pendingMode = DRIVE_MODE;
        driveFrameCount = 0;
        driveLastLog = millis();
    });
    driveWs.onFrame([](PsychicWebSocketRequest *request, httpd_ws_frame *frame) {
        String msg = String((char *)frame->payload, frame->len);
        JsonDocument doc;
        deserializeJson(doc, msg);
        int xRaw = doc["b"].as<int>();
        int yRaw = doc["g"].as<int>();
        int x = map(xRaw, -100, 100, -885, 885);
        int y = map(yRaw, -100, 100, -885, 885);
        targetM1 = constrain(x + y, -855, 855);
        targetM2 = constrain(x - y, -855, 855);
        lastJoyX = xRaw; lastJoyY = yRaw;
        driveFrameCount++;
        driveLastFrame = millis();
        newData = true;
        return ESP_OK;
    });
    driveWs.onClose([](PsychicWebSocketClient *client) {
        targetM1 = 0;
        targetM2 = 0;
        newData = true;
        Serial.println("Drive client disconnected");
    });
    server.on("/ws/drive", &driveWs);

    // --- Tilty WebSocket ---
    tiltyWs.onOpen([](PsychicWebSocketClient *client) {
        Serial.println("Tilty client connected");
        puppetState = PUPPET_IDLE;
        pendingMode = POSITION_MODE;
    });
    tiltyWs.onFrame([](PsychicWebSocketRequest *request, httpd_ws_frame *frame) {
        String msg = String((char *)frame->payload, frame->len);
        JsonDocument doc;
        deserializeJson(doc, msg);
        float tilt = doc["b"].as<float>(); // elevation: -90 to +90
        float pan = doc["g"].as<float>();   // azimuth: -180 to +180
        // Both axes: 0° = center (2048), 0.088 deg/step
        int m1 = CALIB_CENTER + int(tilt / 0.088f);
        m1 = constrain(m1, CALIB_MIN, CALIB_MAX);
        int m2 = CALIB_CENTER + int(pan / 0.088f);
        m2 = constrain(m2, CALIB_MIN, CALIB_MAX);
        targetM1 = m1;
        targetM2 = m2;
        lastBVal = tilt;
        lastGVal = pan;
        lastSeqNum = doc["seq"] | 0;
        newData = true;
        wsFrameCount++;
        return ESP_OK;
    });
    server.on("/ws/tilty", &tiltyWs);

    // --- 2-Motor WebSocket ---
    twoMotorWs.onOpen([](PsychicWebSocketClient *client) {
        Serial.println("2-Motor client connected");
        puppetState = PUPPET_IDLE;
        pendingMode = POSITION_MODE;
    });
    twoMotorWs.onFrame([](PsychicWebSocketRequest *request, httpd_ws_frame *frame) {
        String msg = String((char *)frame->payload, frame->len);
        JsonDocument doc;
        deserializeJson(doc, msg);
        int m1Deg = doc["b"].as<int>();
        int m2Deg = doc["g"].as<int>();
        targetM1 = map(m1Deg, 0, 360, 0, 4095);
        targetM2 = map(m2Deg, 0, 360, 0, 4095);
        newData = true;
        return ESP_OK;
    });
    server.on("/ws/2motor", &twoMotorWs);

    // --- HTTP routes (served from LittleFS) ---
    server.on("/", HTTP_GET, [](PsychicRequest *request, PsychicResponse *response) {
        return serveFile(request, response, "/index.html", "text/html");
    });
    server.on("/drive.html", HTTP_GET, [](PsychicRequest *request, PsychicResponse *response) {
        return serveFile(request, response, "/drive.html", "text/html");
    });
    server.on("/tilty.html", HTTP_GET, [](PsychicRequest *request, PsychicResponse *response) {
        return serveFile(request, response, "/tilty.html", "text/html");
    });
    server.on("/2motor.html", HTTP_GET, [](PsychicRequest *request, PsychicResponse *response) {
        return serveFile(request, response, "/2motor.html", "text/html");
    });
    server.on("/sound.html", HTTP_GET, [](PsychicRequest *request, PsychicResponse *response) {
        return serveFile(request, response, "/sound.html", "text/html");
    });
    server.on("/puppet.html", HTTP_GET, [](PsychicRequest *request, PsychicResponse *response) {
        return serveFile(request, response, "/puppet.html", "text/html");
    });
    server.on("/calibrate.html", HTTP_GET, [](PsychicRequest *request, PsychicResponse *response) {
        return serveFile(request, response, "/calibrate.html", "text/html");
    });
    server.on("/style.css", HTTP_GET, [](PsychicRequest *request, PsychicResponse *response) {
        return serveFile(request, response, "/style.css", "text/css");
    });

    // --- Puppet API ---
    server.on("/api/puppet/start", HTTP_POST, [](PsychicRequest *request, PsychicResponse *response) {
        JsonDocument doc;
        deserializeJson(doc, request->body());
        int pairId = doc["pairId"].as<int>();
        String role = doc["role"].as<String>();
        puppetPairId = pairId;

        if (role == "controller") {
            // Torque off so user can move by hand
            robot.TorqueOFF(BROADCAST);
            delay(50);
            currentMode = -1;
            puppetState = PUPPET_CONTROLLING;
            Serial.printf("Puppet: CONTROLLER, pair %d\n", pairId);
        } else {
            // Puppet: position mode, torque on, ready to receive
            setMotorMode(POSITION_MODE);
            lastPuppetRx = millis();
            puppetState = PUPPET_FOLLOWING;
            Serial.printf("Puppet: FOLLOWING, pair %d\n", pairId);
        }
        return response->send(200, "application/json", "{\"ok\":true}");
    });

    server.on("/api/puppet/stop", HTTP_POST, [](PsychicRequest *request, PsychicResponse *response) {
        puppetState = PUPPET_IDLE;
        setMotorMode(POSITION_MODE);
        Serial.println("Puppet: IDLE");
        return response->send(200, "application/json", "{\"ok\":true}");
    });

    // --- Calibration API ---
    server.on("/api/calibrate/release", HTTP_POST, [](PsychicRequest *request, PsychicResponse *response) {
        if (Serial) Serial.println("CALIB: releasing motors");
        robot.TorqueOFF(BROADCAST);
        delay(50);
        currentMode = -1;
        if (Serial) Serial.println("CALIB: motors released");
        return response->send(200, "application/json", "{\"ok\":true}");
    });

    server.on("/api/calibrate/read", HTTP_GET, [](PsychicRequest *request, PsychicResponse *response) {
        int32_t m1 = readMotorPosition(MOTOR1);
        int32_t m2 = readMotorPosition(MOTOR2);
        if (Serial) Serial.printf("CALIB: read m1=%d m2=%d\n", m1, m2);
        JsonDocument doc;
        doc["m1"] = m1;
        doc["m2"] = m2;
        String out;
        serializeJson(doc, out);
        return response->send(200, "application/json", out.c_str());
    });

    server.on("/api/calibrate/set", HTTP_POST, [](PsychicRequest *request, PsychicResponse *response) {
        if (Serial) Serial.println("CALIB: starting calibration");

        // Step 1: Clear existing offset AND limits to get raw positions
        robot.TorqueOFF(BROADCAST);
        delay(50);
        if (Serial) Serial.println("CALIB: clearing old offsets and limits");
        robot.setHomingOffset(MOTOR1, 0);
        delay(50);
        robot.setHomingOffset(MOTOR2, 0);
        delay(50);
        robot.setMinPositionLimit(MOTOR1, 0);
        delay(50);
        robot.setMaxPositionLimit(MOTOR1, 4095);
        delay(50);
        robot.setMinPositionLimit(MOTOR2, 0);
        delay(50);
        robot.setMaxPositionLimit(MOTOR2, 4095);
        delay(50);
        // Cycle torque for EEPROM changes to take effect
        robot.TorqueON(BROADCAST);
        delay(100);
        robot.TorqueOFF(BROADCAST);
        delay(100);
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
void loop() {
    // Handle mode switch on main thread
    if (pendingMode >= 0) {
        setMotorMode(pendingMode);
        pendingMode = -1;
    }

    // Stats every 5 seconds
    if (Serial && millis() - lastStatsTime > 5000 && wsFrameCount > 0) {
        Serial.printf("STATS t=%lu ws_frames=%u loop_proc=%u client_seq=%u (ws_recv=%.0f%% of sent)\n",
            millis(), wsFrameCount, loopProcessCount, lastSeqNum,
            lastSeqNum > 0 ? 100.0f * wsFrameCount / lastSeqNum : 0);
        lastStatsTime = millis();
    }

    // Puppet following: own smooth update loop
    if (puppetState == PUPPET_FOLLOWING) {
        static float smoothM1 = CALIB_CENTER, smoothM2 = CALIB_CENTER;
        static bool puppetInit = false;
        if (!puppetInit) {
            smoothM1 = targetM1 > 0 ? targetM1 : CALIB_CENTER;
            smoothM2 = targetM2 > 0 ? targetM2 : CALIB_CENTER;
            puppetInit = true;
        }
        if (newData) {
            newData = false;
        }
        // TUNE ME: EMA smoothing for puppet motion
        //   0.1 = very smooth glide, noticeable lag
        //   0.2 = balanced (current)
        //   0.4 = responsive, less smoothing
        //   1.0 = no smoothing (raw positions)
        const float PUPPET_EMA = 0.2f;
        smoothM1 += (targetM1 - smoothM1) * PUPPET_EMA;
        smoothM2 += (targetM2 - smoothM2) * PUPPET_EMA;
        int m1out = constrain((int)roundf(smoothM1), CALIB_MIN, CALIB_MAX);
        int m2out = constrain((int)roundf(smoothM2), CALIB_MIN, CALIB_MAX);
        // Write if changed (no deadband — EMA handles smoothing)
        if (m1out != prevM1) {
            robot.setJointPosition(MOTOR1, m1out);
            prevM1 = m1out;
            delay(1);
        }
        if (m2out != prevM2) {
            robot.setJointPosition(MOTOR2, m2out);
            prevM2 = m2out;
            delay(1);
        }
        delay(8); // ~100Hz update
        // Reset init flag when puppet stops
        if (puppetState != PUPPET_FOLLOWING) puppetInit = false;
        goto loopEnd;
    }

    // Drive watchdog: stop motors if no frame received recently
    if (currentMode == DRIVE_MODE && driveLastFrame > 0 &&
        millis() - driveLastFrame > DRIVE_WATCHDOG_MS &&
        (prevM1 != 0 || prevM2 != 0)) {
        syncWrite(100, 2, MOTOR1, 0, MOTOR2, 0);
        prevM1 = 0; prevM2 = 0;
        targetM1 = 0; targetM2 = 0;
        if (Serial) Serial.printf("DRIVE watchdog: no frame for %lums, stopping motors\n",
            millis() - driveLastFrame);
    }

    // Handle motor commands on main thread (tilty, 2motor, drive)
    if (newData) {
        newData = false;
        loopProcessCount++;
        if (currentMode == DRIVE_MODE) {
            // Periodic drive log: fps + current joystick + motor speeds
            uint32_t now = millis();
            if (now - driveLastLog >= 2000) {
                float fps = driveFrameCount * 1000.0f / (now - driveLastLog);
                bool moving = (targetM1 != 0 || targetM2 != 0);
                if (Serial) Serial.printf("DRIVE %.1fHz joy=(%d,%d) speeds=(%d,%d) %s\n",
                    fps, lastJoyX, lastJoyY, targetM1, targetM2,
                    moving ? "moving" : "stopped");
                driveFrameCount = 0;
                driveLastLog = now;
            }
            // Sync Write: both motors get their PWM in one packet, zero bus delay
            bool isMoving = (targetM1 != 0 || targetM2 != 0);
            syncWrite(100, 2, MOTOR1, targetM1, MOTOR2, targetM2); // reg 100 = Goal PWM, 2 bytes
            prevM1 = targetM1; prevM2 = targetM2;

            // Log state transitions
            if (isMoving && !driveWasMoving) {
                driveZerosSent = 0;
                if (Serial) Serial.printf("DRIVE moving: speeds=(%d,%d) joy=(%d,%d)\n",
                    targetM1, targetM2, lastJoyX, lastJoyY);
            } else if (!isMoving && driveWasMoving) {
                if (Serial) Serial.printf("DRIVE -> stop: writing zeros (gap=%lums)\n",
                    millis() - driveLastFrame);
                driveZerosSent = 1;
            } else if (!isMoving && driveZerosSent > 0 && driveZerosSent <= 5) {
                if (Serial) Serial.printf("DRIVE zero #%lu\n", driveZerosSent);
                driveZerosSent++;
            }
            driveWasMoving = isMoving;
        } else {
            if (Serial) Serial.printf("TILTY t=%lu b=%.2f g=%.2f -> m1=%d m2=%d\n", millis(), lastBVal, lastGVal, targetM1, targetM2);
            if (abs(targetM1 - prevM1) > 10) {
                robot.setJointPosition(MOTOR1, targetM1);
                prevM1 = targetM1;
                delay(1);
            }
            if (abs(targetM2 - prevM2) > 10) {
                robot.setJointPosition(MOTOR2, targetM2);
                prevM2 = targetM2;
                delay(1);
            }
        }
    }

    // Controller mode: read positions and broadcast
    if (puppetState == PUPPET_CONTROLLING) {
        int32_t m1 = readMotorPosition(MOTOR1);
        int32_t m2 = readMotorPosition(MOTOR2);
        if (m1 >= 0 && m2 >= 0) {
            PuppetPacket pkt;
            pkt.pairId = puppetPairId;
            // Convert motor positions to degrees from center
            pkt.tilt = (m1 - CALIB_CENTER) * 0.088f;
            pkt.pan = (m2 - CALIB_CENTER) * 0.088f;
            uint8_t broadcastAddr[] = {0xFF, 0xFF, 0xFF, 0xFF, 0xFF, 0xFF};
            esp_err_t result = esp_now_send(broadcastAddr, (uint8_t *)&pkt, sizeof(pkt));
            static unsigned long lastPuppetLog = 0;
            if (Serial && millis() - lastPuppetLog > 500) {
                Serial.printf("PUPPET TX: pair=%d tilt=%.1f pan=%.1f err=%d\n", pkt.pairId, pkt.tilt, pkt.pan, result);
                lastPuppetLog = millis();
            }
        } else {
            if (Serial) Serial.printf("PUPPET TX: read failed m1=%d m2=%d\n", m1, m2);
        }
        delay(10); // ~100Hz
        return;
    }

loopEnd:
    delay(1);
}

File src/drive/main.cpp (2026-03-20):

/*
 * TiltyBot — All Modes
 *
 * Single firmware serving all control modes.
 * Switch between modes via the index page.
 * Motor control mode is changed when a WebSocket connects.
 *
 * Flash with: pio run -e drive -t upload
 */

#include <Arduino.h>
#include <WiFi.h>
#include <LittleFS.h>
#include <ArduinoJson.h>
#include <PsychicHttp.h>
#include <PsychicHttpsServer.h>
#include "XL330.h"

// ---- Pin config (Waveshare ESP32-S3-Zero) ----
#define RXD2 2
#define TXD2 1
#define RGB_LED 21
#define DRIVE_MODE 16
#define POSITION_MODE 3
#define BROADCAST 254
#define MOTOR1 1
#define MOTOR2 2

// ---- WiFi config ----
const char *ssid = "YOURGROUPNAME";
const char *password = "12345678";

// ---- Globals ----
PsychicHttpsServer server;
PsychicWebSocketHandler driveWs;
PsychicWebSocketHandler tiltyWs;
PsychicWebSocketHandler twoMotorWs;
XL330 robot;
String serverCert;
String serverKey;
int prevM1 = 0;
int prevM2 = 0;
int currentMode = -1;

void setMotorMode(int mode) {
    if (mode == currentMode) return;
    robot.TorqueOFF(BROADCAST);
    delay(50);
    robot.setControlMode(BROADCAST, mode);
    delay(50);
    robot.TorqueON(BROADCAST);
    delay(50);
    currentMode = mode;
    Serial.printf("Motor mode -> %s\n", mode == DRIVE_MODE ? "DRIVE" : "POSITION");
}

// ---- Index page ----
const char index_html[] PROGMEM = R"rawliteral(
<!DOCTYPE html>
<html><head>
<title>TiltyBot 🤖</title>
<meta name="viewport" content="width=device-width,initial-scale=1,user-scalable=no">
<style>
body{background:#111;color:#fff;font-family:sans-serif;display:flex;flex-direction:column;align-items:center;padding:2em}
a{display:block;width:80vw;max-width:400px;margin:0.5em;padding:1em;background:#333;color:#fff;text-align:center;text-decoration:none;border-radius:8px;font-size:1.2em}
a:active{background:#555}
</style></head><body>
<h2>TiltyBot 🤖</h2>
<a href="/drive.html">🚗 Drive Mode</a>
<a href="/tilty.html">🎯 Tilty Mode</a>
<a href="/2motor.html">⚙️ 2-Motor Mode</a>
</body></html>
)rawliteral";

// ---- Drive page ----
const char drive_html[] PROGMEM = R"rawliteral(
<!DOCTYPE html>
<html><head>
<title>TiltyBot Drive</title>
<meta name="viewport" content="width=device-width,initial-scale=1,user-scalable=no">
<style>
html,body{margin:0;height:100%;overflow:hidden;background:#111;color:#fff;font-family:sans-serif;display:flex;flex-direction:column;align-items:center;justify-content:center}
h3{margin:0.5em}
#status{color:#0f0;font-size:0.8em}
label{margin:1em}
canvas{border:2px solid #444;border-radius:50%;touch-action:none}
.back{position:fixed;top:10px;left:10px;color:#888;text-decoration:none}
</style></head><body>
<a class="back" href="/">← back</a>
<h3>Drive 🚗</h3>
<p id="status">Connecting...</p>
<label>Active: <input id="active" type="checkbox"></label>
<canvas id="joy" width="300" height="300"></canvas>
<script>
var ws,active=document.getElementById('active'),status=document.getElementById('status');
var canvas=document.getElementById('joy'),ctx=canvas.getContext('2d');
var cx=150,cy=150,r=130,jx=0,jy=0,touching=false;
function connect(){
  var proto=location.protocol==='https:'?'wss:':'ws:';
  ws=new WebSocket(proto+'//'+location.host+'/ws/drive');
  ws.onopen=function(){status.textContent='Connected';status.style.color='#0f0'};
  ws.onclose=function(){status.textContent='Disconnected';status.style.color='#f00';setTimeout(connect,2000)};
}
connect();
function draw(){
  ctx.clearRect(0,0,300,300);
  ctx.beginPath();ctx.arc(cx,cy,r,0,Math.PI*2);ctx.strokeStyle='#444';ctx.lineWidth=2;ctx.stroke();
  ctx.beginPath();ctx.arc(cx,cy,5,0,Math.PI*2);ctx.fillStyle='#666';ctx.fill();
  var px=cx+jx*r/100,py=cy-jy*r/100;
  ctx.beginPath();ctx.arc(px,py,25,0,Math.PI*2);ctx.fillStyle='#4af';ctx.fill();
}
draw();
function getPos(e){
  var rect=canvas.getBoundingClientRect(),t=e.touches?e.touches[0]:e;
  var dx=t.clientX-rect.left-cx,dy=-(t.clientY-rect.top-cy),dist=Math.sqrt(dx*dx+dy*dy);
  if(dist>r){dx=dx/dist*r;dy=dy/dist*r}
  return{x:Math.round(dx/r*100),y:Math.round(dy/r*100)};
}
canvas.addEventListener('pointerdown',function(e){touching=true;var p=getPos(e);jx=p.x;jy=p.y;draw();send()});
canvas.addEventListener('pointermove',function(e){if(!touching)return;var p=getPos(e);jx=p.x;jy=p.y;draw();send()});
canvas.addEventListener('pointerup',function(){touching=false;jx=0;jy=0;draw();send()});
canvas.addEventListener('pointercancel',function(){touching=false;jx=0;jy=0;draw();send()});
function send(){if(ws&&ws.readyState===1&&active.checked)ws.send(JSON.stringify({b:jx,g:jy}))}
</script></body></html>
)rawliteral";

// ---- Tilty page ----
const char tilty_html[] PROGMEM = R"rawliteral(
<!DOCTYPE html>
<html><head>
<title>TiltyBot Tilty</title>
<meta name="viewport" content="width=device-width,initial-scale=1,user-scalable=no">
<style>
html,body{margin:0;height:100%;overflow:hidden;background:#111;color:#fff;font-family:sans-serif;display:flex;flex-direction:column;align-items:center;justify-content:center}
h3{margin:0.5em}
h4{margin:0.3em;font-weight:normal}
#status{color:#0f0;font-size:0.8em}
label{margin:0.5em}
input[type=range]{width:80vw;max-width:400px}
.back{position:fixed;top:10px;left:10px;color:#888;text-decoration:none}
.vert-container{height:50vh;display:flex;align-items:center;justify-content:center}
.vert-container input{transform:rotate(270deg);width:50vh}
</style></head><body>
<a class="back" href="/">← back</a>
<h3>Tilty 🎯</h3>
<p id="status">Connecting...</p>
<label>Gyro: <input id="active" type="checkbox"></label>
<h4>Pan: <span id="pan">0</span></h4>
<h4>Tilt: <span id="tilt">0</span></h4>
<div class="vert-container"><input id="tiltIn" type="range" min="-179" max="179" value="90"></div>
<input id="panIn" type="range" min="-89" max="89" value="0">
<script>
var ws,active=document.getElementById('active'),status=document.getElementById('status');
var panEl=document.getElementById('pan'),tiltEl=document.getElementById('tilt');
var panIn=document.getElementById('panIn'),tiltIn=document.getElementById('tiltIn');
var b=tiltIn.value,g=panIn.value;
function connect(){
  var proto=location.protocol==='https:'?'wss:':'ws:';
  ws=new WebSocket(proto+'//'+location.host+'/ws/tilty');
  ws.onopen=function(){status.textContent='Connected';status.style.color='#0f0'};
  ws.onclose=function(){status.textContent='Disconnected';status.style.color='#f00';setTimeout(connect,2000)};
}
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

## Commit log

2026-03-20 feat: port to ESP32-S3-Zero with PsychicHttp
    - Replace TinyPICO/ESP32 with Waveshare ESP32-S3-Zero
    - Replace ESP32_HTTPS_Server with PsychicHttp (ESP-IDF native)
    - Use pioarduino platform for ESP-IDF 5.x / Arduino Core 3.x
    - Custom partition table for 4MB flash (1.75MB app + 2.19MB LittleFS)
    - Self-signed EC cert for HTTPS
    - Each mode (drive, tilty, 2motor) is a separate PIO environment
    - Add motor_setup tool for configuring Dynamixel XL330 IDs/baud
    - Drive mode fully implemented with inline HTML joystick
    - Tilty and 2motor modes stubbed out
    - GPIO1/GPIO2 for Dynamixel serial, GPIO21 for RGB LED
    [partitions.csv]
2026-03-20 feat: unified firmware with all three modes
    - Single firmware serves drive, tilty, and 2-motor modes
    - Index page at / with links to each mode
    - Each mode has its own WebSocket endpoint (/ws/drive, /ws/tilty, /ws/2motor)
    - Motor control mode switches automatically when client connects
    - Drive mode stops motors on WebSocket disconnect
    - All HTML inlined in firmware (no LittleFS needed for UI)
    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
2026-03-20 refactor: clean up project structure
    - Rename src/drive/ to src/tiltybot/ to match env name
    - Remove old HTML/JS/CSS data files (UI is now inlined in firmware)
    - Keep only SSL certs in data/
    - Move motor commands to main loop for thread safety
    - Update comment header with correct flash command
    - LittleFS only used for SSL certificates
    [main.cpp]
2026-03-20 docs: update README for ESP32-S3-Zero + PsychicHttp
    - Replace TinyPICO references with Waveshare ESP32-S3-Zero
    - Document wiring (GPIO1+GPIO2 for Dynamixel data)
    - Add motor setup instructions
    - Document unified firmware with all modes
    - Update project structure and PIO environments
    - Add SSL cert regeneration instructions
    - Note 8+ char WiFi password requirement
2026-03-20 docs: update workshop guide for ESP32-S3-Zero
    - Rewrite EN guide for new hardware and unified firmware
    - Remove TinyPICO-specific instructions
    - Add motor setup tool instructions
    - Simplify mode selection (index page instead of platformio.ini)
    - Add TODO markers for screenshots that need updating
    - Mark JP guide as needing translation update
2026-03-21 feat: add sound recorder page
    - Inline sound recorder HTML/JS in firmware
    - Restyled to match dark theme
    - Accessible from index page
    - Records audio via phone mic, plays back through phone/BT speaker
    - Purely client-side, no motor interaction
    - Removed old LittleFS sound files
2026-03-21 feat: add HTTP->HTTPS redirect on port 80
    - Run second HTTP server on port 80 that redirects all requests to HTTPS
    - Users can type http://192.168.4.1 and get redirected automatically
    - Fixes Android Chrome defaulting to http:// when no protocol specified
    [main.cpp]
2026-03-21 chore: add blank KiCad project for ESP32-S3-Zero dynashield
    - Blank schematic, PCB, and project files for KiCad 8
    - README with wiring table and SnapEDA part import instructions
    - ESP32-S3-Zero mounts underneath via castellated holes
    - B3B-EH-ALFSN connector for Dynamixel XL330
    [dynasheild.kicad_pcb, dynasheild.kicad_sch, dynashield-s3.kicad_pcb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]
2026-04-03 feat(sound): add file upload, trim controls, fix metadata race condition
    [main.cpp]
2026-04-07 feat: add puppet mode, tilty smoothing, calibration test, no-cache headers
    - Puppet mode: ESP-NOW based robot-to-robot mirroring with emoji pairing
    - Tilty: low-pass filter, gimbal lock protection, 30Hz throttle, float pan mapping
    - Calibration test: standalone tool for homing offset and position limits
    - Serve HTML with no-cache headers to prevent stale pages
    - Use XL330 fork with setHomingOffset/setMinPositionLimit/setMaxPositionLimit
    - Conditional serial logging (only when monitor connected)
    - Add logs/ to gitignore
    [main.cpp]
2026-04-07 chore: remove calibration test (debugging tool, no longer needed)
    [main.cpp]
2026-04-07 feat(tilty): replace Euler angles with RelativeOrientationSensor quaternions
    - Use Android RelativeOrientationSensor for hardware quaternion input
    - Delta quaternion from reference pose with YXZ Euler decomposition
    - Eliminates gimbal lock (singularity moved to tilt=±90°, unreachable)
    - Tilt/pan crosstalk reduced to ~18° (from 100°+ jumps)
    - Add calibration page with homing offset and position limit controls
    - Add analysis/plotting scripts for tilty logs
    - TODO: measure tilt limit from robot body, add gain multiplier
    [main.cpp]
2026-04-08 fix(puppet): ESP-NOW interface, motor reads, degree-based packets
    - Fix ESP_ERR_ESPNOW_IF: set peer.ifidx = WIFI_IF_AP for AP-only mode
    - Fix controller motor reads: use readMotorPosition() (echo-skip)
    - Send degrees instead of raw positions so each robot uses own calibration
    - Add BOT_SSID build flag for compile-time SSID configuration
    - Add puppet debug logging (throttled)
    - Update README with puppet, calibration, tilty gyro docs
    - Update workshop guide with calibration + puppet sections
    - Update TODO (mark completed items, add new tasks)
    - Replace puppet emojis
    [main.cpp]
2026-04-08 docs: remove pre-assembly zeroing instructions (calibration replaces it)
2026-04-08 fix(puppet): stop puppet mode when entering any other mode
    [main.cpp]
2026-04-08 fix(calibrate): slow down test sequence, add tilt direction note
    [main.cpp]
2026-04-08 fix(calibrate): use profile velocity for slower test movements
    [main.cpp]
2026-04-08 fix(tilty): negate tilt for reversed motor installation
2026-04-08 feat(puppet): add EMA smoothing for puppet following
    Puppet motor updates run at ~100Hz with EMA (alpha=0.2) to smooth
    received positions. Eliminates jerk when controller stops after fast
    movement. No deadband — every position change writes to motor.
2026-04-08 feat(sound): add text-to-speech with saved phrase buttons
    Uses Web Speech API (works offline). Type text and press Enter or
    Speak button. Save button creates reusable phrase buttons. Phrases
    persist in localStorage. Voice selector for available system voices.
2026-04-08 fix(drive): sync write, watchdog, reliable stop
    - Sync Write (Dynamixel 0x83) sends both motor PWM values in one
    packet so motors start/stop simultaneously with zero inter-motor delay
    - Drive watchdog stops motors after 300ms with no client frames
    - Always write both motors on every 10Hz heartbeat frame so stop
    commands are never lost to a single dropped bus packet
    - Transition logging: moving/stopped state changes, zero write count,
    frame gap on stop
    - targetM1/M2 marked volatile for dual-core safety
    - Joystick: 10Hz heartbeat, dead-man switch (300ms no-move releases),
    document-level pointerup catches finger sliding off canvas
    - TODO: apply sync write to position modes (tilty, puppe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
    [main.cpp]
2026-04-15 docs(workshop): split intro/advanced and move media to assets
    - Add TiltyBot_Intro_EN.md with browser-first workshop flow
    - Add TiltyBot_Advanced_EN.md for technical setup/debug details
    - Move legacy EN/JP workshop guides into assets/ to keep root clean
    - Rename img/ -> assets/ and update markdown image paths
    - Add new phone screenshots and robot photo used in Intro
    - Keep demo GIFs (ConeBot, drive, tilty) in relevant sections
2026-04-15 docs: simplify README, consolidate guides
    - README trimmed to overview + GIFs + links to guides
    - Intro: phone screenshots at width=320, link renamed
    - Advanced: renamed to Assembly & Advanced, absorbed hardware/
    wiring/motor setup/CLI reference from README
